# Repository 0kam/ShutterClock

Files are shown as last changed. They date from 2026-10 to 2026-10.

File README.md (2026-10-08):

# ShutterClock

定点カメラ（タイムラプス・フェノロジー観測）用の低消費電力インターバルタイマです。
Nikon デジタル一眼レフをリモート端子から有線レリーズし、12 V ソーラー充電バッテリーからカメラへ給電することもできます。
時刻合わせ・撮影スケジュール設定・撮影ログ回収は、スマホ（Android Chrome）の Web Bluetooth ページで行います。
積雪深ロガー [SnowGauge](https://github.com/0kam/SnowGauge) の姉妹プロジェクトです。

*ShutterClock is a low-power BLE interval timer for fixed-point cameras: XIAO nRF52840 (Zephyr), wired Nikon remote release via optocouplers, optional camera power from a 12 V solar battery, Web Bluetooth field app. Documentation is in Japanese.*

## 状態（2026-10-08）

基板 v1.0 を JLCPCB に発注済み（5 枚、10 月中旬到着予定）。回路は独立レビュー済み、ブレッドボードでの実機確認はこれから。初期決定事項と未決事項を [設計仕様書 v0.12](ShutterClock_設計仕様書_v0.12.md) にまとめています。
対象機種は D7200・D7500（必須）と D7000・D7100・D800・D810（任意）。D7500 の消費電流は実測済み。次は部品の到着後にブレッドボードで降圧モジュール・時計保持経路・撮影検出を確認し、ファームウェアを SnowGauge から流用します。

## 開発者向け

- 設計仕様書（要件・設計判断・未決事項・改版履歴）: [ShutterClock_設計仕様書_v0.12.md](ShutterClock_設計仕様書_v0.12.md)
- 部品購入リスト（ブレッドボード試作）: [docs/01_parts.md](docs/01_parts.md)（[CSV](docs/01_parts.csv)）
- SnowGauge から流用したファイルの一覧: [PROVENANCE.md](PROVENANCE.md)
- 作業引き継ぎ（AI エージェント向け）: [CLAUDE.md](CLAUDE.md)

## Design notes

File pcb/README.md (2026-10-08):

# ShutterClock PCB v1.0 (ordered 2026-10-08, JLCPCB W2026100808086019 / Y14-13437881A, 5 pcs)

- Board: **100 x 88 mm**, 2-layer. Bottom layer is a GND pour; most signals on top,
  the VIN trunk and a few long signals on the bottom.
- Mounting: 4x M3 (3.2 mm) holes, centres 3.5 mm from each edge (93 x 81 mm spacing).
- Generated by [generate_board.py](generate_board.py) (+ [tracks.py](tracks.py)) →
  `ShutterClock.kicad_pcb` (KiCad 10). **Never hand-edit the .kicad_pcb.**
  Run: `/Applications/KiCad/KiCad.app/Contents/Frameworks/Python.framework/Versions/Current/bin/python3 generate_board.py`
  then `kicad-cli pcb drc --severity-error --severity-warning --format json --output drc.json ShutterClock.kicad_pcb`
  and `python3 drc_report.py`. Current state: **DRC 0 errors, 0 unconnected** (46 warnings: silkscreen overlaps, library-name notes).
- Gerbers: `ShutterClock_v1.0_gerbers.zip` (JLCPCB: 2 layers, 1.6 mm, HASL, defaults). Renders: `render_top.png`, `render_bottom.png`.
- Circuit: spec v0.11 §6 (independent review applied). BOM: `../docs/01_parts.md`.

## Open items (ordered before bench verification — check these when the boards arrive)

1. U2 (MBC2596-01) hole positions (±19.0 / ±8.0 mm from the module centre) were judged
   correct by the user from the module photo; confirm with the real module on the bare board.
2. Bench-verify the circuit on the breadboard first (spec §6.5): LM2596 + 4700 µF with the
   D7500 (and D7200), keep-alive follower voltage, shot detection on A1.
3. Independent layout review (as for SnowGauge v1.2) — not done yet.
4. XIAO SMD-pad clearance to the KA_EN / CAM_EN tracks is at the 0.2 mm minimum; fine for
   JLCPCB but do not tighten.

## Firmware pin map (single source of truth for the board)

| XIAO pin | Net | Function |
|---|---|---|
| A0 (D0) | ADC_NODE | Battery voltage: VIN × 100k/(1M+100k) (ungated divider, 100 nF). Reading × 11 |
| A1 (D1) | A1_NODE | Camera current: 0.1 Ω low-side shunt in the camera return (CAM_N), 10 kΩ + 100 nF. 1 A = 0.1 V |
| D2 | AF_DRV | PC817 U4 (AF / half-press) via 1 kΩ. High = pressed |
| D7 | CAM_EN | Camera supply: Q3 → Q2 → MBC2596-01 (9.4 V) → 1N5822 → CAM_P. High = on |
| D8 | SHUT_DRV | PC817 U3 (SHUTTER / full-press) via 1 kΩ. High = pressed |
| D9 | BTN | Test-shot / BLE button SW1 to GND (enable the internal pull-up) |
| D10 | KA_EN | Keep-alive path: Q6 → Q5 → 10 Ω → Q7 follower (≈ 7.3–8.5 V) → CAM_P. High = on |
| 3V3 | 3V3_SYS | From U1 (NJW4181U3-33B) through JP1 |
| GND | GND | |
| D3–D6, 5V | — | unused (reachable on the XIAO castellations) |

Rules: never drive CAM_EN and KA_EN so that the camera is released on the keep-alive
path; enter keep-alive only from CAM_EN = on; drop to CAM_EN = on if A1 shows > 50 mA
during keep-alive; low-battery cutoff 11.5 V.

## Connectors and jumpers

- J1 (5.08 mm screw terminal, bottom-left): battery + / − (12 V lead-acid / LiFePO4; fuse F1 5 A, Q1 reverse protection, 2x P4KE15A TVS)
- J2 (5.08 mm screw terminal, bottom-right): camera + / − → Nikon EP-5B cable. The − side is the sense shunt — keep it as the only camera ground.
- J3 (3.5 mm stereo jack, right edge): tip = SHUTTER, ring = AF, sleeve = common → off-the-shelf 3.5 mm → MC-DC2 / 10-pin release cables (verify the cable's pinout with a meter)
- JP1 (near the XIAO): shunt fitted normally; **remove before connecting USB** to the XIAO (same rule as SnowGauge)
- JP2 (below Q3): shunt fitted = camera supply always on (bypasses Q3)
- U2: 4-pin module socket positions; set the trimpot to **9.4 V** and remove the module's LED before fitting

## Silkscreen notes

"REMOVE JP1 BEFORE USB", "U2: SET 9.4V, REMOVE LED", "JP2=ALWAYS ON", battery and camera polarity, diode cathodes marked "K".

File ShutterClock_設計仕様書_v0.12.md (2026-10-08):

# ShutterClock 設計仕様書 v0.12

- 版: v0.12(2026-10-08)
- 名称: **ShutterClock**
- 目的: 定点カメラ(タイムラプス・フェノロジー観測)の Nikon デジタル一眼レフを、低消費電力タイマで決まった時刻に有線レリーズする。必要に応じてソーラー充電の 12V バッテリーからカメラへ給電する
- 姉妹プロジェクト: SnowGauge(commit `36e21f8` / FW `fw-2026-09-07b` から分岐。流用ファイルは `PROVENANCE.md` に記録)
- 運用ポリシー: 本仕様書を唯一の真実(single source of truth)とし、変更時は毎回版を上げる

---

## 1. 位置づけ

- SnowGauge で実証済みの基盤(Zephyr FW、時計モデル、LittleFS 記録+内蔵フラッシュミラー、BLE アドバタイズ、SMP、WDT・診断、Web Bluetooth ページ)を流用し、「センサ測定」の代わりに「カメラのレリーズ」と「カメラ電源の制御」を行う。
- 撮影 1 回ごとに本体側にもレコードを残し、画像の EXIF 時刻と照合できるようにする(カメラ時計のずれ、撮り損ねの検出)。

## 2. 初期決定事項(2026-10-06 時点)

| 項目 | 決定 |
|---|---|
| 対象機種 | **必須: D7200、D7500**。対応したい: D7000、D7100、D800、D810(§2.1) |
| MCU | Seeed XIAO nRF52840(非 Sense で可)、NCS v3.4.0 / Zephyr。Adafruit ブートローダ維持、MCUboot なし、書き込みは USB シリアル DFU のみ |
| レリーズ | Nikon リモートケーブル 3 線(GND / AF / SHUTTER)、フォトカプラ 2 個(AF、SHUTTER)、スリープ中は両方 OFF。シーケンス: AF ON → 待ち(カメラ起床、300〜500ms 目安、実機で調整)→ SHUTTER ON(~200ms)→ 両方 OFF。AF を常時 GND に落とすのは禁止(半押し状態が続き測光が眠らない) |
| レンズ | MF(AF の合焦待ち・合焦失敗によるレリーズ不可を避ける) |
| 入力電源 | 12V 鉛 / LiFePO4、ソーラーチャージコントローラ経由。入力側の全部品を 30V 以上の定格で設計(充電時 14.8V、バッテリー外れ時の PV 開放電圧)。ヒューズ + TVS + P-MOSFET 逆接保護(カメラ系 2A 以上) |
| 3.3V | 30V 以上入力の低 Iq LDO(SnowGauge の NJU7223 は 14V 定格で不可) |
| カメラ電源 | 9V の降圧モジュール(EN 付き)をピンヘッダ実装し(v0.4: D7500 のピーク 3〜4A を実測。2A 級の D36V28F9 は不足。v0.7 案は秋月の LM2596 モジュール MBC2596-01 + 4,700µF、§6.2・U28)、Nikon のダミーバッテリー(カプラー)へ給電。EN は GPIO、ジャンパで常時 ON も選べる。9V 出力の電流検出は任意(カメラ起動・カード書き込み完了の判定用)。常時給電か撮影ごと給電かは待機電流の実測後に決める(U8) |
| 電池電圧監視 | ゲート付き分圧。30V 入力時に ADC ノード < 3.0V |
| スケジュール・BLE・SMP・現地ページ | SnowGauge と同じ構成と UI ルール(大きなボタン、ピッカー、破壊的操作は 2 タップ)。BLE 名 `SC-XXXX`。ページは https://0kam.github.io/ShutterClock/app/ |
| 記録 | 1 トリガ 1 レコード(時刻、seq、flags、vbat、温度、カメラ電流(実装時))→ EXIF 時刻と照合 |
| 工程 | 実カメラでブレッドボード → 実測(picowatt)→ PCB(`pcb/generate_board.py` で生成、手編集禁止、kicad-cli で DRC、JLCPCB 用ガーバー zip)→ 発注前に独立設計レビュー。**ShutterClock はユーザー本人が組み立てる(学生組立ではない)ので表面実装部品も可(v0.9)**。SnowGauge のスルーホール優先ルールは本機には適用しない |

### 2.1 対象機種と機種差(v0.2)

| 機種 | 優先 | リモート端子 | 電池 / ダミーバッテリー | USB(カメラ側、純正ケーブル) | 内蔵無線 |
|---|---|---|---|---|---|
| D7200 | 必須 | アクセサリーターミナル(MC-DC2 系) | EN-EL15 系 / EP-5B | 8 ピン独自形状(UC-E6 / UC-E17) | Wi-Fi + NFC |
| D7500 | 必須 | アクセサリーターミナル(MC-DC2 系) | EN-EL15a / EP-5B | micro-B(UC-E20) | SnapBridge(BLE + Wi-Fi) |
| D7000 | 任意 | アクセサリーターミナル(MC-DC2 系) | EN-EL15 / EP-5B | mini-B(UC-E4) | なし |
| D7100 | 任意 | アクセサリーターミナル(MC-DC2 系) | EN-EL15 / EP-5B | 8 ピン独自形状(UC-E6) | なし(WU-1a アダプタ) |
| D800 | 任意 | 10 ピン | EN-EL15 / EP-5B | USB 3.0 micro-B | なし |
| D810 | 任意 | 10 ピン | EN-EL15 系 / EP-5B | USB 3.0 micro-B | なし |

- **電源は 6 機種とも EN-EL15 系 + EP-5B(パワーコネクター)で共通**。純正 AC アダプタ EH-5b 系は 9V 出力なので、本体側の 9V 降圧で全機種をまかなえる。
- **レリーズは 6 機種とも同じ 3 線(GND / 半押し / 全押し)**で、違うのはカメラ側のコネクタだけ。10 ピンは 4 番 = 全押し、9 番 = 半押し、6 番 = 信号 GND(pinouts.ru の MC-22 ピン配置。現物で要確認)。→ 接続方式は U27。
- USB は機種ごとに形が違うので、§4.2 の案では「スマホ用 OTG アダプタ(USB-C → USB-A メス)+ 各機種の純正ケーブル」を使う。

## 3. 未決事項

決め方: 【実機】実カメラ・ブレッドボードで測って決める /【判断】使い方・運用で決める /【調査】データシート・資料で決まる。§5 の測定番号 M# と対応。

### 3.1 カメラ本体(最優先: ほぼすべてがこれで決まる)

| # | 項目 | 論点 | 決め方 |
|---|---|---|---|
| ~~U1~~ | ~~対象カメラ機種~~ | **解決(v0.2)**: 必須 D7200・D7500、任意 D7000・D7100・D800・D810(§2.1) | — |
| U2 | AF → SHUTTER のタイミング | 半押しタイマーオフ(スタンバイ)からの起床時間、SHUTTER パルス幅の下限、連続トリガの最小間隔 | 【実機】M3 |
| U3 | 消費電力 | **D7500 実測(v0.4、`docs/measurements/2026-10-07_d7500_current.md`)**: 9V 給電で待機(半押しタイマーオフ)= 電源スイッチ OFF = **0.42mA**(測定中に 0.60 → 0.42mA へ低下。時計リセット直後だったので時計用電池の充電分と推定)。1 ショット(MF、半押しタイマー 4 秒)**2.7A·s ≈ 0.75mAh@9V**、うち約 85% は撮影後に起きている約 10 秒。半押しタイマー 6 秒だと 3.2A·s。AF は +3% 程度。電源スイッチ ON / OFF のたびにセンサークリーニング(約 2 秒、各 1.2〜1.3A·s)。残: D7200 | 【実機】M1, M2 |
| U4 | 給電再投入時の挙動 | **D7500 実測(v0.4)**: 電源スイッチ ON のまま給電すると**自動で起動する**(0.54 秒で起床、センサークリーニングなし)。リモートを全押しにしたまま給電すると **1.95 秒後にレリーズ**(起動〜撮影可能の上限値)。残: D7200、時計リセット状態(日時設定画面)でもレリーズできるか | 【実機】M4 |
| U5 | カメラ内蔵時計の保持 | 時計は内蔵の充電式電源で動き、主電池(または EP-5B 給電)から必要に応じて充電される(Nikon 説明書)。撮影ごと給電で 1 日の通電が数分しかないと、充電が足りず数か月で時計がリセットされる恐れ(D7000〜D7200 の説明書では「約 2 日の充電で約 3 か月」、要確認)。待機電流が 0.60 → 0.42mA へ下がった実測(v0.4)は、待機中も時計用電池が充電されることを示唆する。**実例(v0.4)**: 試験に使った D7500 は電源 ON 時に日時設定画面を出した(しばらく電池なしで置かれ、時計がリセットされていた)。対策候補: 定期的に一定時間通電する、常時給電にする、**時刻の正は ShutterClock のレコードとし、ファイル番号とレコードを 1 対 1 で対応づける**(U10 の撮影検出が前提) | 【実機】M5【判断】 |
| U6 | カメラ設定チェックリスト | 撮影直後の画像表示、半押しタイマー、ファイル番号の連番、画質と SD 容量(撮影数/日 × 期間 × ファイルサイズ)、日時、MF 設定などを設置手順書にまとめる | 【判断】U1 後 |

### 3.2 カメラ電源方式

| # | 項目 | 論点 | 決め方 |
|---|---|---|---|
| U7 | ダミーバッテリーの種類 | 全機種 EP-5B で共通(v0.2)。純正 EP-5B + 本体の 9V か、互換品(12V 直入力や USB-C 給電のものもある)か。12V 直入力品なら降圧モジュールが不要になり、ハイサイドスイッチだけで済む。互換品は機種(特に D7500)で認識されない恐れ | 【調査】【実機】 |
| U8 | 常時給電 vs 撮影ごと給電 | 撮影ごと給電なら「EN ON → 起動待ち → AF/SHUTTER → 書き込み完了待ち → EN OFF」。書き込み中に切ると画像・カード破損の恐れがあるので、完了判定(固定の待ち時間か電流検出か)が必要。D7500 実測(v0.4)、1 日 6 ショット・9V 側: 常時給電 ≈ 15mAh/日 ≈ 0.13Wh/日 + 降圧モジュールの自己消費(D36V50F9 は 12V で 0.6〜1.2Wh/日、カメラより大きい)。撮影ごと給電(書き込み直後に切る、1 回約 2.5 秒)≈ 0.013Wh/日。12V 20Ah(240Wh)+ ソーラーに対してはどちらも小さく、効くのはパネルが数か月覆われる場合だけ。撮影ごと給電の残課題: 書き込み完了の判定、時計用電池の充電不足(U5)。**推奨(v0.4、未決): 既定は常時給電(単純、時計が保たれる、書き込み中の遮断がない)、EN 制御は残して低電圧時のカメラ遮断と撮影ごと給電モードに使う** | 【判断】 |
| U28 | カメラ電源のピーク電流 | **D7500 実測(v0.4)**: 1 ショットでピーク 3.0〜3.2A(最大 4.1A、2A 超が 20〜30ms、ミラー・シャッターチャージ時)、電源スイッチ ON 時 3.9A。**安定化電源の電流制限 2A ではレリーズせず「Err」**、4A なら正常。D36V28F9(連続 2.6A 標準)は不足 → 候補だった D36V50F9 は国内で取り扱いなし(v0.5 調査)→ **v0.7 案: 秋月の LM2596 モジュール MBC2596-01(¥1,900、ピーク電流制限 3.4A 以上、制限時も停止しない)+ 4,700µF**。予備 DFR1015 / D30V33MAS(§6.2 に必要容量の計算)。実物で撮影できるかはブレッドボードで確認 | 【実機】 |
| U29 | 時計保持用の微小電力経路 | U2(LM2596)の Iq 5mA では時計保持の通電(1 時間/日)が年 24Wh になる(§6.2)。**v0.9 案: 2SJ334 スイッチ + 2SK4017 フォロワ + ツェナー基準の別経路で 8〜9V を供給、U2 出力にショットキーで逆流防止(§6.1)**。必要な通電時間の根拠: Nikon の説明書(D7000〜D7200)の「約 2 日の充電で約 3 か月」(要確認)→ 比例なら 1 日あたり約 32 分、1 時間/日で 2 倍の余裕 | 【実機】M5 |
| U9 | 降圧モジュールの自己消費と EN の駆動 | D36V28F9 / D36V50F9 の資料値: 無負荷時 1〜3mA / 2〜4mA、スリープ時は EN→VIN の 100kΩ プルアップ等で 10〜20µA/V(12〜14.8V で約 120〜300µA)。**EN は VIN にプルアップされているので GPIO に直結しない**(GPIO に VIN が回り込む)。N-MOSFET のオープンドレインで引き下げる。MCU 停止時にカメラ電源を ON / OFF のどちらに倒すか、上流にロードスイッチを入れて µA 級まで切るかを決める | 【判断】【実機】M6 |

### 3.3 撮影成否の確認

| # | 項目 | 論点 | 決め方 |
|---|---|---|---|
| U10 | 撮れたことの検出 | **v0.5 案: (a) をカメラ側 GND の 0.1Ω シャントで実装(§6)。1A 超 = レリーズした、待機レベルに戻った = 書き込み完了 → 撮影ごと給電の遮断判定にも使う。** U5 の「レコードを時刻の正とする」方式を採るなら必須。(a) 9V 出力の電流検出(シャント + INA 系。カード書き込みの電流波形で判定、撮影ごと給電の完了判定にも使える)/ (b) ホットシューの X 接点(シンクロ接点)を GPIO で読む(露光時に閉じる。安価でスルーホール可。高速シャッター時の挙動と GND 共通化は要確認)/ (c) 検出しない(後で EXIF と照合) | 【判断】【実機】 |
| U11 | 失敗時の扱い | 未検出時の再試行回数、電池低下時に撮影をスキップする閾値、スキップ理由のレコード化 | 【判断】 |

### 3.4 入力電源・電源回路

| # | 項目 | 論点 | 決め方 |
|---|---|---|---|
| U12 | 電源の取り口 | チャージコントローラの LOAD 端子(コントローラの低電圧遮断に任せる)か、バッテリー直結(ファームで低電圧遮断)か。LOAD 端子だと遮断・復帰のたびに本体がリセットされる(時計は SnowGauge と同じ ESTIMATED 復帰で足りるか) | 【判断】 |
| U13 | バッテリー・パネル・コントローラ | **v0.5: 主に鉛 12V 20Ah、寒くない場所では LiFePO4 も使う。目標は 20Ah で約 1 年(ソーラーなしでも)。** 容量・機種は未定。LiFePO4 は 0°C 未満で充電不可(冬季運用ならコントローラの低温充電保護が必要)、鉛は温度補償 | 【判断】 |
| ~~U14~~ | ~~3.3V LDO の選定~~ | **決定(v0.9)**: NJW4181U3-33B(SOT-89、35V / 40V abs、Iq 9µA、¥60、秋月 113996)を基板に直接実装。ユーザーが組み立てるので表面実装可。入力に 100Ω + 10µF の RC(§6.1) | — |
| U15 | サージ・逆接保護の整合 | **v0.5 案: 秋月の TVS は P4KE15A まで → 2 本直列(スタンドオフ 25.6V、クランプ約 42V)。LDO(40V)の前に 47Ω + 10µF の RC を入れて保護。逆接保護は 2SJ334 + 15V ツェナー(§6)。** TVS のスタンドオフ電圧(> 14.8V、PV 開放電圧も考慮)とクランプ電圧に、LDO・降圧モジュール・MOSFET が耐えるか。逆接保護 P-MOSFET の Vgs 定格(30V 入力ならツェナーでゲートをクランプ) | 【調査】 |
| U16 | 電池分圧のゲート方式 | **v0.5 案: ゲートで切らず 1MΩ / 100kΩ を常時接続(12µA、予算の約 1%)。ADC ノードは 30V 入力で 2.7V、定格超過の経路がない(§6)。** 参考: ローサイドで切ると OFF 時に ADC ノードが入力電圧まで引き上げられる(nRF52840 の絶対最大定格違反。SnowGauge 仕様書 v0.10 で独立検証により見つかった件と同種)。ハイサイド(P-MOSFET + レベルシフト)で切るなど、OFF 時もノードが VDD を超えない構成にする | 【調査】 |

### 3.5 スケジュール・ファームウェア・アプリ

| # | 項目 | 論点 | 決め方 |
|---|---|---|---|
| U17 | スケジュールの表現 | **v0.5: 典型は 7〜18 時に毎時 1 枚(12 枚/日)→ (b) で表せる。** (a) 時刻リスト(例 10:00 / 12:00 / 14:00)、(b) 時間窓 + 間隔(SnowGauge 型)、(c) 日の出・日の入り基準(同期時の緯度経度から本体で計算)。併用可。最短間隔は U4・U8 で制約される | 【判断】 |
| U18 | 1 トリガあたりの枚数 | N 枚連続レリーズするか(カメラ側の露出ブラケットとの組み合わせ) | 【判断】 |
| U19 | 設置作業モード | アプリから「カメラ電源 ON(N 分後に自動 OFF)」「テスト撮影」「AF のみ」。撮影ごと給電にするなら、フレーミング中にカメラを起こしておく手段が必須 | 【判断】 |
| U20 | レコード形式 | SnowGauge は 40B 固定 + CRC-16。候補項目: UNIX 時刻、seq、flags(時計状態、撮影確認、スキップ理由、再試行)、vbat(無負荷 / カメラ負荷時)、温度(nRF 内蔵)、カメラ電流ピーク・書き込み時間、起床〜完了の所要時間 | 【判断】 |
| U21 | アドバタイズの中身 | 電池電圧、撮影数、最終撮影の成否、時計状態など | 【判断】 |
| U22 | チャンネル数 | カメラ 1 台固定か、2 チャンネル(2 台・別スケジュール)を用意するか。フォトカプラとコネクタの追加だけなので基板設計前に決めたい | 【判断】 |
| ~~U27~~ | ~~リモートケーブルの接続方式~~ | **決定(v0.3)**: 本体に 3.5mm ステレオジャック(スルーホール)を付け、インターバロメータ用に市販されている「3.5mm → MC-DC2」「3.5mm → 10 ピン」ケーブルで全機種に対応する。チップ / リング / スリーブの割り当て(一般にチップ = 全押し、リング = 半押し、スリーブ = GND)は購入品をテスターで確認する | — |
| U23 | テスト撮影画像の確認 | §4 の案のどれを採るか | 【判断】【実機】M7 |

### 3.6 筐体・設置・その他

| # | 項目 | 論点 | 決め方 |
|---|---|---|---|
| U24 | 筐体 | カメラハウジング(市販 / 自作)と制御箱の分け方、ケーブルグランド、結露・レンズの曇りや霜(ヒーターは電力収支に大きく効く) | 【判断】 |
| U25 | 運用条件 | 使用温度範囲(カメラのカタログ値は多くが 0〜40°C)、設置期間、巡回頻度 | 【判断】 |
| U26 | ライセンス | public リポジトリ(SnowGauge も未設定)。例: ファーム・アプリ MIT、基板 CERN-OHL-P | 【判断】 |

## 4. テスト撮影と画像確認(案)

### 4.1 基本(追加ハードなし)

アプリの「テスト撮影」ボタン(BLE)→ 本番と同じ有線レリーズ経路で撮影 → カメラ背面液晶の再生で確認。成否は U10 の検出があればアプリに表示する。

### 4.2 推奨候補: Android の USB OTG + WebUSB でカメラから直接画像を取る(本体ハード追加なし)

- 設置時だけ、スマホ(Android の Chrome)とカメラの USB 端子を OTG ケーブルでつなぐ。同じ Web ページが WebUSB で PTP(Picture Transfer Protocol)を話す。ShutterClock 本体には何も足さない。
- 流れ: BLE で ShutterClock にテスト撮影を指示(本番のレリーズ経路を試せる)→ PTP で新しい画像の追加を待つ → `GetThumb`(埋め込みサムネイル、約 160×120)または `GetObject`(JPEG 本体)→ ページに表示して構図・ピントを確認。
- おまけ: カメラの時計を PTP の日時プロパティでスマホ時刻に合わせられる(EXIF 照合が楽になる)。電池残量・カード空き容量も読める。将来はライブビュー(Nikon 独自コマンド)でのフレーミングも可能。
- 実現性の根拠: Chrome の WebUSB は PTP(Still Image クラス)を遮断していない。Google の web-gphoto2(libgphoto2 を WebAssembly + WebUSB に移植)は Android と macOS で追加設定なしに動くとされる。
- 途中結果(v0.3、D7500): OTG アダプタでスマホとつないだ状態でもシャッターは切れた。ただしスマホ側がカメラを認識していたかは未確認(Android の「開くアプリ」の選択画面は出なかった)。PTP セッションを開いた状態での確認は web-gphoto2 デモで行う。
- 制約: Android のみ(iPhone は Bluefy を含め WebUSB 非対応 → 4.1 に縮退)。Windows はドライバの差し替えが必要。カメラの USB 端子にハウジング内で手が届く必要がある。USB 接続中に有線レリーズが効くかは機種依存(M7)。効かなければ PTP の `InitiateCapture` で撮る(この場合は本番経路の試験にならない)。
- 実装方針: web-gphoto2(WASM で数 MB、LGPL)は組み込まず、必要な PTP 操作(セッション開始、イベント待ち、オブジェクト一覧、サムネイル / 本体取得、日時設定)だけを JS で手書きする。数百行規模の見込み。
- 着手前の確認(コード不要): 手持ちの Android + OTG アダプタ + 各機種の純正 USB ケーブル(§2.1)で web-gphoto2 のデモ(https://web-gphoto2.rreverser.com/)を開き、接続・撮影・プレビューができるか見る。手順と記録表は `docs/measurements/2026-10-07_webusb_ptp_check.md`。ここで動けばこの案は筋が良い。
- 6 機種すべてに使える(USB ケーブルの形が違うだけ)のが、4.3 のカメラ内蔵無線に対する利点。

### 4.3 機種依存・代替

- カメラ内蔵無線を設置時だけ使う: 開発ゼロ。ただし別アプリで、ShutterClock のページとは統合されない。対象機種では D7500(SnapBridge)と D7200(内蔵 Wi-Fi。旧アプリ Wireless Mobile Utility が今のスマホで動くかは要確認)だけで、D7000 / D7100 / D800 / D810 には使えない。
- Wi-Fi SD カード(ezShare 等): 本体の改造は不要だが、別アプリと Wi-Fi の切り替えが要る。常時給電時の消費と信頼性に難があり非推奨。

### 4.4 将来案(重い): ShutterClock 自身を USB ホストにする

nRF52840 は USB デバイス専用なので、SPI 接続の USB ホストコントローラ(MAX3421E。Zephyr に UHC ドライバあり、USB ホストスタックは実験的)を足し、PTP を自前実装してサムネイル(数 KB)を BLE で送る。巡回時にハウジングを開けずに最新画像を確認できるのが利点だが、ハード・ファーム・消費電力がすべて増えるため v1 では見送る。

## 5. 最初の実測(実カメラ + 安定化電源 + picowatt)

| # | 測るもの | 方法 | 決まる未決事項 |
|---|---|---|---|
| M1 | カメラ待機電流(電源スイッチ ON・半押しタイマーオフ / スイッチ OFF) | 安定化電源 9V → EP-5B、picowatt で電流 | U3, U8 |
| M2 | 1 ショットの電流プロファイル(起床・露光・カード書き込み)と mAh | 同上、リモートケーブルの AF/SHUTTER を手動スイッチで | U3, U8, U10 |
| M3 | スタンバイから AF → 撮影可能までの時間、SHUTTER パルス幅の下限 | フォトカプラ + 手元の MCU で遅延を振る | U2 |
| M4 | 給電再投入 → 自動起動の有無と撮影可能までの時間 | 電源 ON/OFF を繰り返す | U4, U8, U17 |
| M5 | 長時間無給電後の時計保持 | 一晩〜数日無給電にして日時を確認 | U5 |
| M6 | 降圧モジュールの自己消費(EN=Low / 無負荷、12V 入力) | picowatt | U9 |
| M7 | USB(PTP)接続中に有線レリーズが効くか、web-gphoto2 デモの動作 | Android + OTG アダプタ + 純正 USB ケーブル(`docs/measurements/2026-10-07_webusb_ptp_check.md`) | U23 |

測定はまず必須機種の D7200・D7500 で行い、任意機種は M7(数分で済む)だけでも見ておく。

実施状況(v0.4): M1・M2・M4 を D7500 で実施(`docs/measurements/2026-10-07_d7500_current.md`、picowatt 3200Sa/s、AF / MF、半押しタイマー 6 秒 / 4 秒)。M7 は OTG 接続中のレリーズのみ確認(§4.2)。

## 6. 回路・部品構成(v0.11、独立レビュー反映済み)

前提: 撮影ごと給電を既定(U8)、典型 12 枚/日、鉛 12V 20Ah で約 1 年。部品は秋月優先、次にスイッチサイエンス(SS)、海外通販は不可。**表面実装部品は可(v0.9、ユーザーが組み立てるため)**。カメラ電源出力はネジ端子(EP-5B のケーブルを直接つなぐ)。在庫・価格は 2026-10-07 時点。ピン割り当て・電気トポロジの正は今後 `pcb/README.md` に移す。

### 6.1 構成

```
J1 BAT+ ─ F1 5A ─ Q1 2SJ334(D→S、G は R15 1MΩ で GND、ZD1 15V G-S)─ VIN ─┬─ D1+D2 P4KE15A(直列)─ GND、C1 100µF/50V
                                                                      ├─ R4 100Ω ─ C2 10µF ─ U1 NJW4181 ─ C4 2.2µF ─ JP1 ─ XIAO 3V3(C6 0.1µF)
                                                                      ├─ R1 1MΩ ─ ADC_NODE(C7 0.1µF → A0)─ R2 100kΩ ─ GND
                                                                      ├─ Q2 2SJ334(S)…(D)─ U2 MBC2596-01(9.4V)─ D4 1N5822 ─┐
                                                                      │    Q2 G: R12 100kΩ → VIN、ZD2 15V G-S、R16 33kΩ → Q3 2SK4017 D(JP2 で常時 ON)
                                                                      │    Q3 G ← R8 1kΩ ← D2(CAM_EN)、R10 100kΩ → GND
                                                                      └─ Q5 2SJ334(S)…(D)─ KA_SW ─ R19 10Ω/1W ─ Q7 2SK4017 D、Q7 S ─────┴─ CAM+ ─ C3 4700µF、R17 1MΩ(ブリーダ)─ J2(+) → EP-5B
                                                                           Q5 G: R13 100kΩ → VIN、ZD3 15V G-S、R18 33kΩ → Q6 2SK4017 D
                                                                           Q6 G ← R9 1kΩ ← D10(KA_EN)、R11 100kΩ → GND
                                                                           Q7 G ← R5 47kΩ ← KA_SW、Q7 G ─ ZD4 9.1V ─ D6 1N4148 ─ GND(基準 ≈ 9.7V、Q5 ON 時のみ約 60µA)
J2(−)= CAM− ─ R3 0.1Ω 3W ─ GND(スター接続)、CAM− ─ R14 10kΩ ─ A1(C8 0.1µF)
D3(AF)─ R6 1kΩ ─ U3 PC817 ─ R20 100Ω ─ J3 リング      D8(SHUTTER)─ R7 1kΩ ─ U4 PC817 ─ R21 100Ω ─ J3 チップ      U3/U4 エミッタ ─ J3 スリーブ
D9 ─ SW1 ─ GND(テスト撮影・BLE 起動、内部プルアップ)     J4: D4/D5(I2C)・D6/D7・3V3・GND 予備ヘッダ
```

独立レビュー(2026-10-07、サブエージェント)で修正した点:
- Q2/Q5 のゲートと 2SK4017 の間に **33kΩ**(R16/R18)。Vgs は 11V で −8.3V(完全 ON)、14.8V で −11V(ツェナー非動作)、20V 以上で −15V にクランプ(30V で 0.45mA、ON 中のみ)。Q5 側にも ZD3。
- Q1 のゲート抵抗は **1MΩ**(10kΩ だと常時 1.1〜1.5mA = 年 150Wh 超)。向きは D = 電池側、S = VIN、ZD1 のカソードは S。
- 時計保持フォロワの基準は **KA_SW(Q5 の後)から R5 47kΩ** で取り、常時バイアスをなくす。ZD4 は 9.1V + 1N4148(10V ツェナーは秋月に無い)→ 基準 ≈ 9.7V、出力 ≈ 7.3〜8.5V(常に降圧より低く、Q2 ON 中は Q7 が電流を持たない)。Q7 ドレインに **10Ω/1W**(C3 への突入電流 ≤ 1.3A)。
- ファーム規則: 時計保持へは降圧 ON の状態からだけ入る(C3 が 9V のまま)、時計保持中はレリーズしない、時計保持中に A1 > 50mA なら Q2 ON に戻す。低電圧遮断は **11.5V**(11V では LM2596 がピーク時にドロップアウト)。
- **JP1**: U1 出力と XIAO 3V3 の間(USB 接続時に外す。シルク「REMOVE JP1 BEFORE USB」)。**JP2**: Q3 D-S 間(カメラ常時 ON)。
- フォトカプラ LED 抵抗は **1kΩ**(約 2mA。nRF52840 の標準駆動は 2mA)。J3 のチップ・リングに **100Ω** 直列。C3 に **1MΩ** ブリーダ。
- A0 分圧 1M/100k は 42V クランプ時に 3.8V(注入 0.2µA、C7 で緩和)→ 許容。SAADC: 内部 0.6V 基準、ゲイン 1/6、取得時間 ≥ 10µs、オーバーサンプル。基板ごとにゲイン定数を校正。
- 電流検出: ゲイン 1(FS 0.6V)で 1.46mA/LSB。R3 の GND 側・J1(−)・XIAO GND を 1 点で結ぶ(ケルビン配線)。カメラ GND への第 2 経路(ホットシュー等)は作らない。
- D4 の逆方向漏れ(1N5822: 0.1mA@25°C、高温で最大 1mA)は時計保持中に U2 側へ流れる → 温間で実測、大きければ低漏れ品か P-FET 理想ダイオードに。
- TVS 2 本直列のブレークダウンは 28.6〜31.6V: 30V 連続ならショート故障 → F1 が切れる(フェイルセーフ)。

- 3.3V は NJW4181U3-33B 1 段(動作 5〜35V、絶対最大 40V、Iq 9µA 標準 / 20µA 最大、100mA、±1%、サーマル・過電流・逆電流保護内蔵、Cin 0.1µF・Co 2.2µF セラミック可、−40〜+85°C、ピン 1 = VOUT / 2 = GND / 3 = VIN)。TVS クランプ(最大 42V)が絶対最大 40V を超えうるので、入力に R4 100Ω + C2 10µF の RC を置く(100Ω は BLE 送信の 15mA ピークでも 1.5V しか落ちない)。**代案(表面実装を避ける場合)**: Q4 2SK4017 フォロワ + 9.1V ツェナー + NJU7223F33 の 2 段(Iq 約 50µA)。
- カメラ系は Q2 で降圧モジュールの手前から切る(EN で止めるより漏れが少ない。SnowGauge の Q1/Q2 と同じ方式)。MCU 停止時は OFF 側に倒れる。ジャンパで常時 ON にもできる(ソーラーが十分な現場向け)。
- 撮影ごと給電のシーケンス(案): Q2 ON → AF+SHUTTER を保持(または約 2.5 秒待ってから AF → SHUTTER)→ R3 で 1A 超を検出 = レリーズ確認 → 待機レベル(< 50mA 程度)に戻るのを待つ = 書き込み完了 → Q2 OFF。
- **時計保持用の微小電力経路(U29)**: 撮影用の降圧 U2 は動作中に 5mA 食うので、時計の充電のためにカメラを待機状態(0.42mA)で 1 時間/日 通電する用途には使わない。代わりに Q5 → Q7(2SK4017 ソースフォロワ、ゲートをツェナー ZD4 で固定)の経路で約 8〜9V を供給する。消費は通電中のツェナーバイアス約 60µA とカメラ待機電流だけ(常時バイアスなし、v0.11)。U2 の出力には D4(ショットキー 1N5822、3A。5A のスルーホール品は秋月に無く、4A ピークは 20〜30ms なので可)を入れ、U2 が停止中に出力側から逆流しない(LM2596 は入力無電圧で出力に電圧がかかる状態を想定していない)ようにする。D4 の分だけ U2 は 9.4V に調整する。ZD4 は 9.1V + 1N4148(レビュー反映、v0.11)(出力 = Vz − Vgs ≈ 8〜9.5V を狙う)。
- 時計保持のシーケンス(案): 各撮影の書き込み完了後、Q5 ON → Q2 OFF(カメラは待機のまま、電圧 9 → 8〜9V)→ N 分後に Q5 OFF。12 枚/日 × 5 分 = 1 時間/日。追加の起動なし。N はアプリから設定可能にする。
- D4/D5(I2C)、D6/D7 は予備としてヘッダに出す。

### 6.2 カメラ用 9V(U28)

降圧モジュールの電流上限を超える分はコンデンサで補える。実測 17 ショットのうち最悪のケース(ピーク 4.1A)で、上限を超える電荷と、9V から 1V 下がるまでに必要な容量:

| 上限 | 超過電荷(最悪) | 必要容量(1V 低下) |
|---|---|---|
| 2.0A | 14.7mA·s | 約 15,000µF(非現実的。安定化電源 2A 制限で Err になったのと整合) |
| 2.5A | 3.7mA·s | **約 3,700µF → 4,700µF で可** |
| 3.0A | 0.7mA·s | 700µF |
| 3.3A | 0.5mA·s | 470µF |

ただし上限到達時にモジュールが「電流を抑えて出力を下げる」のか「停止(ヒカップ)する」のかで結果が変わるので、ブレッドボードで実物を確認する。

| 案 | 部品 | 入手 | 価格 | 評価 |
|---|---|---|---|---|
| **A(本命)** | **MBC2596-01**(HTC Korea、LM2596-ADJ 搭載、入力 4〜35V、出力 1.25〜30V を多回転ポテンショで調整、定格 2A・最大 3A、43×21mm、4 端子 IN+/IN−/OUT+/OUT−、基板上に 100µF/50V・220µF/35V・47µH、赤 LED)+ **C3 4,700µF/16V** | **秋月 131750** | ¥1,900 | **LM2596 のピーク電流制限は 3.6/4.5/6.9A(25°C)、全温度で 3.4A 以上**。制限時は周波数を下げて電流を抑える 2 段方式で、停止(ヒカップ)しない → 3.4A を超える分(最悪 0.5mA·s)はコンデンサで余裕をもって補える。動作時 Iq 5mA 標準 / 10mA 最大(ON/OFF ピンは端子に出ていないので Q2 で上流を切る)。IC の入力は動作 40V / 絶対最大 45V(TVS クランプ 42V 以下)。**LED(約 7mA)は外す。出力電圧は組立時にテスターで 9.0V に合わせ、ポテンショを固定する**。在庫 19(2026-10-07、10 月中旬補充予定) |
| B(予備) | DFRobot DFR1015(入力 7.5〜30V、9V 2.5A 連続 / 3.5A ピーク、出力はパッドで 9V 固定)+ C3 | SS 8601 | ¥1,172 | 搭載 IC・電流制限の挙動が未記載。調整不要なのは利点 |
| C(予備) | Pololu D30V33MAS(出力可変 → 9.0V、入力〜45V、3.3A 連続、EN、逆接 40V) | SS 9640 | ¥7,692 | 余裕はあるが高価 |
| 不可 | D36V50F9 / D36V28F9 | 国内取り扱いなし | — | — |
| 不可 | 秋月 AZ1084C-5.0(5A LDO) | 秋月 117599 | ¥50 | 入力 12V まで、TO-252(表面実装) |
| 不可 | 秋月の降圧キット(YDS512F など) | — | — | 入力 17〜20V 以上が必要 |

LM2596 の効率(資料の曲線): 入力 12V・出力 12V・3A で約 88%、出力 9V・0.3A 付近では 80〜85% と見る。動作時 Iq 5mA は撮影中(10 秒 × 12 回/日)なら無視できるが、**時計保持のために毎日 1 時間通電すると 5mA × 13V × 1h ≈ 0.065Wh/日(年 24Wh)になる**。秋月の 9V レギュレータ(NJM7809 / LM78L09 / BA09CC0T / BA90DD0T 等)はいずれも自己消費 mA 級で、NJW4181 の 8V 版は在庫がない → 低消費の 9V 降圧に替える道はないので、**時計保持は §6.1 の微小電力経路(U29)で行う(年約 3Wh)**。

### 6.3 部品表(草案、1 台分)

**購入リストの正は `docs/01_parts.md`(+ CSV、2026-10-07、秋月コード確認済み)**。以下は設計上の要点のみ。

| 記号 | 部品 | 型番 | 入手(コード) | 単価 | 備考 |
|---|---|---|---|---|---|
| A1 | マイコン | Seeed XIAO nRF52840(非 Sense) | 秋月 117341 | ¥1,780 | SS 8145 は品切れ |
| U1 | 3.3V LDO | **NJW4181U3-33B**(SOT-89-3、35V / 40V abs、Iq 9µA、100mA) | 秋月 113996 | ¥60 | U14 決定。基板に直接実装 |
| R4, C2 | U1 入力の RC | 100Ω 1/4W + 10µF/50V(電解または積セラ) | 秋月 | — | TVS クランプ 42V から U1(40V abs)を守る |
| U2 | 9V 降圧 | **MBC2596-01**(LM2596-ADJ モジュール、9.4V に調整、LED を外す) | 秋月 131750 | ¥1,900 | §6.2。予備 DFR1015(SS 8601)/ D30V33MAS(SS 9640) |
| D4 | U2 出力の逆流防止 | ショットキー 1N5822(40V 3A) | 秋月 102229 | 10 本 ¥350 | 時計保持中に U2 へ逆流させない。発熱が気になれば 2 本並列 |
| Q5, Q6 | 時計保持経路のハイサイドスイッチ | 2SJ334 + 2SK4017(Q2/Q3 と同じ) | 秋月 102846 / 107597 | ¥110 / ¥30 | GPIO D10 |
| Q7 | 時計保持用フォロワ | 2SK4017 | 秋月 107597 | ¥30 | 出力 ≈ Vz − Vgs ≈ 8〜9V、負荷 0.4〜0.6mA |
| ZD4, D6, R5 | Q7 ゲート基準 | 9.1V ツェナー BZX55C9V1 + 1N4148 + 47kΩ(KA_SW から) | 秋月 115721 / 100941 | 20 本 ¥100 / 50 本 ¥200 | バイアス約 60µA、Q5 ON 中のみ |
| Q1, Q2 | P-ch MOSFET | 2SJ334(−60V、38mΩ@−10V、±20V) | 秋月 102846 | ¥110 | ピン G-D-S |
| Q3 | N-ch MOSFET | 2SK4017(60V、Vth 1.3〜2.5V) | 秋月 107597 | ¥30 | ピン G-D-S |
| ZD1, ZD2 | Q1/Q2 ゲート保護 | 15V ツェナー GDZJ15C | 秋月 107498 | ¥10 | 入力 30V 超でも Vgs を 15V に制限 |
| D1, D2 | TVS(2 本直列) | P4KE15A | 秋月 129633 | 10 本 ¥150 | 合成でスタンドオフ 25.6V、クランプ約 42V(U15) |
| F1 | ヒューズ | 5.2×20mm 5A(普通溶断 MF51NR)+ クリップ FUC-03A ×2 | 秋月 107131 / 110521 | ¥40 / ¥20 | 5A のタイムラグ品は秋月になし。4A×30ms のピークは I²t で問題なし。クリップの電流定格は未確認 |
| R3 | 電流検出 | 0.1Ω 3W ±1%(RSMF3BR100F) | 秋月 111011 | ¥20 | 225mA → 22.5mV、4A → 0.4V |
| R1, R2 | 電池分圧 | 1MΩ / 100kΩ | 秋月(SnowGauge と同じ) | — | ゲートなし(U16) |
| U3, U4 | フォトカプラ | PC817X3NSZ1B(Sharp) | 秋月 113765 | ¥30 | 在庫少。代替 UPC817CG(116090) |
| J3 | 3.5mm ステレオジャック | MJ-8435 | 秋月 109060 | ¥90 | 1 = スリーブ、2 = チップ、3 = リング |
| C1 | 入力コンデンサ | 100µF/50V ハイブリッド(Rubycon 50PZF100M10X9) | 秋月 116871 | ¥80 | |
| C3 | 9V 側バルク | 電解 4,700µF/16V(Rubycon ZLH 16ZLH4700MEFC16X25、φ16×25mm、低インピーダンス品) | 秋月 114096 | ¥100 | §6.2。LM2596 の電流制限(最小 3.4A)を超えるピークの補償。計算上は 1,000µF で足りるが温度・D7200 未測定の余裕 |
| SW1 | タクトスイッチ | 6mm | 秋月 103647 | ¥15 | |
| J1, J2 | ネジ端子 2P 5.08mm | TB111-2 | 秋月 102333 | ¥40 | J1 電池、J2 カメラ電源(EP-5B のケーブルを直接。v0.6 決定) |
| — | ダミーバッテリー | Nikon EP-5B | Amazon.co.jp など国内 | 約 ¥2,300 | |
| — | レリーズケーブル | 3.5mm → MC-DC2 型 | Amazon.co.jp(例: 「3.5mm-N3」) | 約 ¥900 | チップ/リング/スリーブはテスターで確認。10 ピン用は国内に 3.5mm 品がなく 2.5mm 品 + 変換が必要 |

### 6.4 電力見積もり(12 枚/日、ソーラーなし)

| 項目 | 1 日あたり |
|---|---|
| ShutterClock(MCU・BLE・NJW4181・分圧・Q1 ゲート、約 50µA) | 0.016Wh |
| 撮影 12 回(1 回 ≈ 3.05A·s @9V、降圧効率 88%) | 0.10Wh |
| カメラ系 OFF 中(Q2 で遮断) | ≈ 0 |
| 時計保持 1 時間/日(U29 の経路、カメラ待機 0.42〜0.6mA @13V) | 0.006〜0.008Wh |
| **合計** | **約 0.13Wh/日 → 年約 47Wh** |

鉛 20Ah(240Wh)は放電深度 50%・自己放電を見込むと 1 年で使えるのは 60〜120Wh 程度 → ソーラーなしでもほぼ 1 年。LiFePO4 なら余裕あり。常時給電(降圧の無負荷電流が 24 時間流れる)は 1 年の目標に合わない。

### 6.5 ブレッドボードで確認すること(発注前)

1. MBC2596-01(9.0V に調整、LED 除去)+ 4,700µF で D7500(と D7200)が Err なく撮影できるか、撮影中の 9V の落ち込み(picowatt の vbus)、12V 入力時の無負荷電流
2. 撮影ごと給電のシーケンス(§6.1)と、R3 の電流でのレリーズ確認・書き込み完了の判定
3. NJW4181 + XIAO の待機電流(SnowGauge は NJU7223 込みで 32µA だった)
5. 時計保持経路: Q7 の出力電圧(ZD4 の値決め)、U2 停止中に D4 で逆流が止まること、待機状態の通電で時計用電池が充電されること(M5: 通電 1 時間/日で数週間後に時計が合っているか)
4. 購入したレリーズケーブルのチップ / リング / スリーブ

## 7. 進め方(案)

1. 対象機種は決定済み(§2.1)。EP-5B、リモートケーブル(U27)、OTG アダプタを用意する
2. M1〜M7 を測る(ブレッドボード以前、手動スイッチで可)→ U2〜U5、U7〜U9 を決める
3. 回路案(電源入力・LDO・降圧・フォトカプラ・分圧・電流検出)→ ブレッドボード
4. FW: SnowGauge から流用(`PROVENANCE.md` に記録)→ レリーズ・カメラ電源制御 → レコード → テスト撮影 / 状態 GATT → ページ
5. ブレッドボード実機で消費電流を実測 → PCB → 独立設計レビュー → 発注

## 8. 改版履歴

| 版 | 日付 | 内容 |
|----|---|---|
| v0.1 | 2026-10-06 | 初版。初期決定事項(§2)、未決事項 U1〜U26(§3)、テスト撮影画像の確認案(§4)、最初の実測項目 M1〜M7(§5) |
| v0.2 | 2026-10-06 | **対象機種を決定(U1 クローズ)**: 必須 D7200・D7500、任意 D7000・D7100・D800・D810。§2.1 機種差の表を新設(全機種 EP-5B 共通、レリーズは 3 線共通でコネクタのみ MC-DC2 系 / 10 ピン、USB 形状は機種ごと)。U5 に時計の充電式電源と「レコードを時刻の正とする」案、U7 を EP-5B 前提に、U9 に D36V28F9 の資料値と EN をオープンドレインで駆動する注意、U10 に U5 との関係、**U27(3.5mm ジャック + 市販変換ケーブル案)を追加**。§4.2 に明日の確認手順書へのリンク、§4.3 を対象機種の内蔵無線に合わせて更新 |
| v0.3 | 2026-10-07 | **U27 決定(3.5mm ジャック + 市販変換ケーブル)**。**D7500 の電流を実測(M1・M2)**: 待機 ≈ スイッチ OFF ≈ 0.60mA@9V、1 ショット 3.3A·s(約 8 割は撮影後の待機)、ピーク 3.1A(電源 ON 時 3.9A)、電流制限 2A で「Err」→ **U28(ピーク電流)を追加**、U3・U8 に実測値と判断の目安。§4.2 に OTG 接続中もレリーズできた途中結果 |
| v0.4 | 2026-10-07 | **D7500 の追加測定(AF / MF、半押しタイマー 6 / 4 秒、給電の入れ直し)**: 待機 0.42mA(時計リセット直後の 0.60mA から低下)、1 ショット 2.7A·s(MF・4 秒)、センサークリーニングは電源スイッチ ON / OFF のみ。**U4: 給電で自動起動、全押し保持で 1.95 秒後にレリーズ**。U5 に時計リセットの実例。U8 に 1 日あたりの見積りと推奨(既定は常時給電、未決)。**U28: 最大 4.1A、候補を D36V50F9 に**。§2 カメラ電源の行を更新 |
| v0.5 | 2026-10-07 | **§6 回路・部品構成案(草案)を新設**: 秋月・SS での入手性を調査(海外通販不可)。撮影ごと給電を前提に Q2 でカメラ系を遮断、9V は SS の Pololu D30V33MAS(D36V50F9 は国内取り扱いなし、秋月 AZ1084C は入力 12V まで)、3.3V は RT9069 / NJW4183(表面実装、40V)、TVS は P4KE15A ×2、電流検出 0.1Ω、分圧はゲートなし。12 枚/日で年 45〜65Wh の見積もり。U10・U13〜U17 に v0.5 の案と前提(典型 7〜18 時毎時、鉛 20Ah で 1 年)を追記。旧 §6・§7 を §7・§8 に |
| v0.6 | 2026-10-07 | ユーザー決定: **表面実装不可**、カメラ電源出力はネジ端子。§6.2 にピーク補償の計算(2.5A 上限なら 4,700µF で可、2.0A は 15,000µF で非現実的)→ **9V は DFRobot DFR1015 + 4,700µF を本命、D30V33MAS を予備**。**3.3V は 2SK4017 フォロワ + 9.1V ツェナー + NJU7223F33 の 2 段**(U14、代案 LP2950)。§6.1・§6.3・§6.5 を更新 |
| v0.7 | 2026-10-07 | **9V 降圧を秋月の MBC2596-01(LM2596-ADJ モジュール、ユーザー提案)に変更**: 資料とデータシートを確認(ピーク電流制限 3.4〜6.9A、2 段の周波数低減方式で停止しない、Iq 5mA、入力 40V、ON/OFF ピンは端子なし、LED 要除去、ポテンショで 9.0V に調整)。DFR1015 / D30V33MAS は予備に。§6.2 に時計保持通電と Iq 5mA の影響(年 24Wh)を追記 |
| v0.8 | 2026-10-07 | **3.3V LDO を NJW4181U3-33B(ユーザー提案)に変更(判断待ち)**: データシート確認(動作 5〜35V、絶対最大 40V、Iq 9/20µA、100mA、保護内蔵、セラミック可、ピン VOUT-GND-VIN)。SOT-89 を変換基板 AE-SOT89 に載せてスルーホール扱いにする案、入力に 100Ω + 10µF の RC。フォロワ + NJU7223F33 は代案に。§6.4 の本体消費を約 35µA に |
| v0.9 | 2026-10-07 | ユーザー決定: **ShutterClock は本人が組み立てるので表面実装可** → U14 クローズ(NJW4181U3-33B を基板に直接実装)。**U29 時計保持用の微小電力経路を追加**(秋月の 9V レギュレータは mA 級、NJW4181 8V 版は在庫なしのため): 2SJ334 + 2SK4017 フォロワ + ツェナー、U2 出力にショットキー D4、U2 は 9.4V に調整、撮影後に 5 分 × 12 回 = 1 時間/日。§6.1・§6.3・§6.4(年約 47Wh)・§6.5 を更新。U5 に説明書の「2 日で 3 か月」と待機中充電の示唆 |
| v0.10 | 2026-10-07 | ユーザー決定: 電圧下限の試験はせず 9V 方針を維持、U2 は MBC2596-01(DFR1015 より資料が揃い入力耐圧が高い)。**`docs/01_parts.md` + CSV を新設**(秋月コード・価格・在庫を確認)。D4 を 1N5822(3A)に、ZD4 を 12V に(5A スルーホール品・11V ツェナーは秋月に無い) |
| v0.11 | 2026-10-07 | **独立設計レビュー(サブエージェント)を反映**: Q2/Q5 ゲートに 33kΩ 直列 + Q5 にも 15V ツェナー(BLOCKER)、Q1 ゲート抵抗 1MΩ(BLOCKER、10kΩ は年 150Wh)、時計保持の基準を KA_SW から 47kΩ + 9.1V ツェナー + 1N4148 に(常時バイアス廃止)、Q7 に 10Ω/1W、JP1(USB)・JP2(常時 ON)、PC817 LED 1kΩ、J3 に 100Ω、C3 に 1MΩ ブリーダ、低電圧遮断 11.5V、ケルビン配線の注意。§6.1 を v0.11 回路に差し替え。PCB v1.0 草案を生成(`pcb/generate_board.py`、100×88mm、DRC エラー 0、ガーバー出力済み、未発注。U2 の穴位置は実測待ち、ピンマップは `pcb/README.md`) |
| v0.12 | 2026-10-08 | **PCB v1.0 を JLCPCB に発注**(注文 W2026100808086019 / PCB Y14-13437881A、2 層 100×88mm、5 枚、緑、1.6mm、HASL、1oz、合計 $13.75、UPS Express Saver 2〜4 営業日、配送先 自宅)。U2 の穴位置はユーザー確認済み。ブレッドボード検証とレイアウトレビューは基板到着までに並行して行う |

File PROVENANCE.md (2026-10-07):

# Provenance

Files copied from [SnowGauge](https://github.com/0kam/SnowGauge).
Fork point: commit `36e21f8` (FW `fw-2026-09-07b`).

When a bug is fixed on either side, check this table and port the fix by hand.
Add a row whenever a file is copied; update "Changes" when it diverges.

| ShutterClock path | SnowGauge source path | SnowGauge commit | Changes |
|---|---|---|---|
| `pcb/lib/XIAO-nRF52840-DIP.kicad_mod` | `pcb/lib/XIAO-nRF52840-DIP.kicad_mod` | `36e21f8` (file unchanged since `b0c9c5e`) | none — same XIAO footprint (14 through-hole pads, 15.24 mm rows) |
| `pcb/generate_board.py` (structure) | `pcb/generate_board.py` | `36e21f8` | rewritten for the ShutterClock netlist; same pcbnew approach (nets → footprints → tracks → outline → GND pour → silk) |

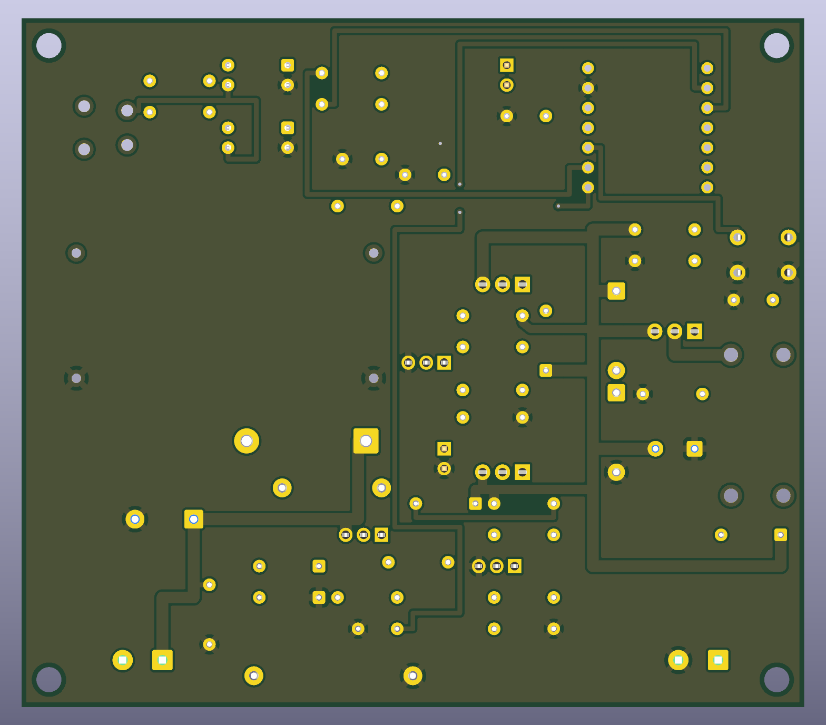
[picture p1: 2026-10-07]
pcb/render_bottom.png

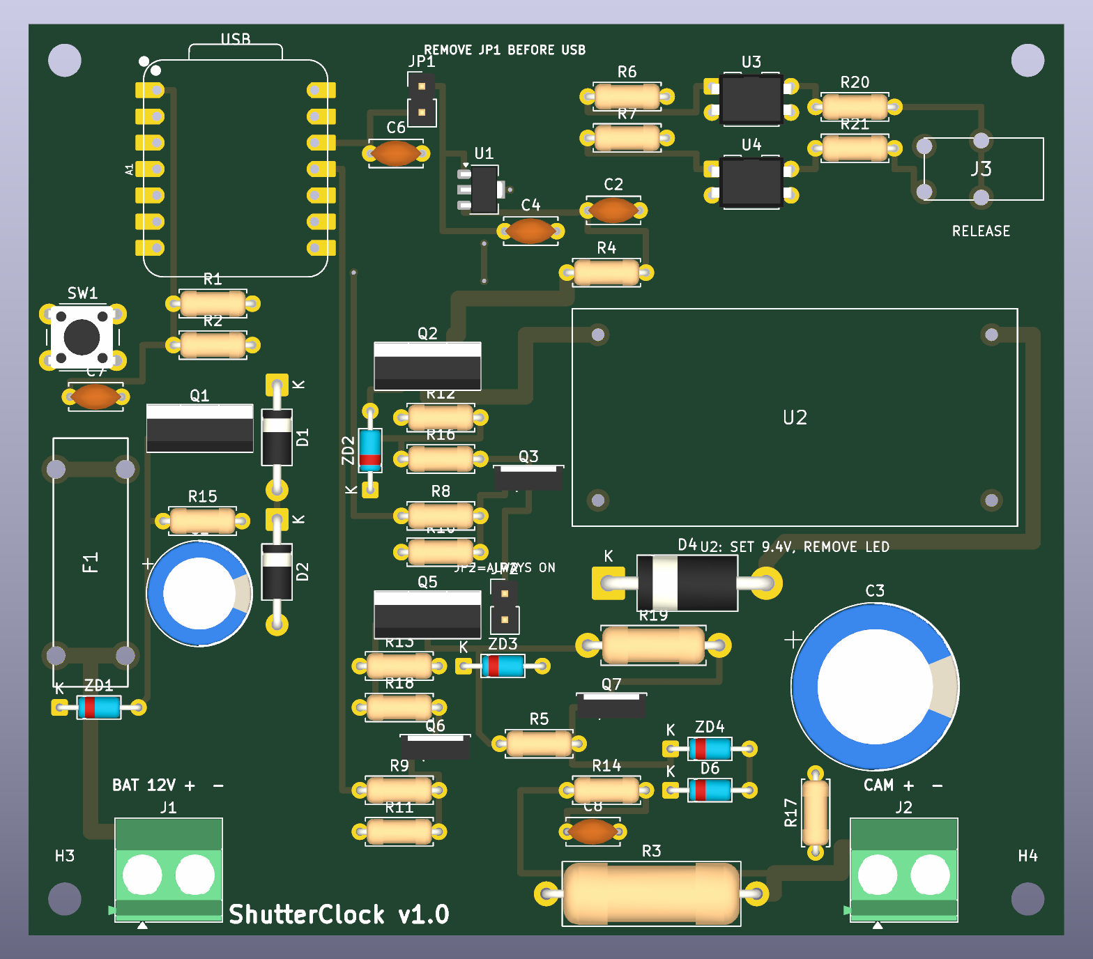
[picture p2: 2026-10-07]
pcb/render_top.png

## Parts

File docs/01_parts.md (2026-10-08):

# 01. 部品購入（ShutterClock 部品表 / BOM）

対象: **ブレッドボード試作（2026-10 発注分）**。回路は設計仕様書 v0.11 §6（独立レビュー反映済み）で、PCB 化の前にブレッドボードで検証します。
購入先は秋月電子を優先し、カメラ側のアクセサリは Amazon.co.jp です。価格・在庫は 2026-10-07 時点（税込）。

> 設計の根拠は [設計仕様書](../ShutterClock_設計仕様書_v0.12.md) §6、電気的なつながりの正は（PCB 設計後）`pcb/README.md` に移します。
> 注文用の CSV（同じ内容）: [01_parts.csv](01_parts.csv)

## 1. 買い方の目安

| 作るもの | 必要な表 |
|---|---|
| ブレッドボード試作（1 台） | (a) 回路部品 + (b) ブレッドボード用 + (c) カメラ側 |
| PCB 版（後日） | (a) + (d)。基板は JLCPCB |

秋月は 10 本・20 本・100 本売りの部品が多いので、「数量」は**回路 1 台に載る個数**、「備考」に販売単位を書いています。

## 2. 部品表

### (a) 回路部品（1 台分）

| 記号 | 部品 | 値/型番 | 数量 | 購入先 | 単価 | 備考 |
|---|---|---|---|---|---|---|
| A1 | マイコン（BLE） | Seeed **XIAO nRF52840**（非 Sense、秋月表記「XIAO BLE nRF52840」） | 1 | [秋月 117341](https://akizukidenshi.com/catalog/g/g117341/) | ¥1,780 | 在庫 269。予備 +1 推奨 |
| U1 | 3.3 V LDO（常時 ON） | **NJW4181U3-33B**（SOT-89、入力 5〜35 V、Iq 9 µA、100 mA） | 1 | [秋月 113996](https://akizukidenshi.com/catalog/g/g113996/) | ¥60 | 表面実装。ブレッドボードでは変換基板 AE-SOT89 に載せる（(b)） |
| U2 | カメラ用 9 V 降圧 | **MBC2596-01**（LM2596-ADJ モジュール、入力 4〜35 V、3 A） | 1 | [秋月 131750](https://akizukidenshi.com/catalog/g/g131750/) | ¥1,900 | **在庫僅少、10 月中旬入荷予定**。2 個買って 1 個予備。組立時に出力を **9.4 V** に調整、赤 LED を外す |
| Q1, Q2, Q5 | P-ch MOSFET（逆接保護 / カメラ電源スイッチ / 時計保持スイッチ） | **2SJ334**（−60 V / −30 A） | 3 | [秋月 102846](https://akizukidenshi.com/catalog/g/g102846/) | ¥110 | ピン G-D-S。10 個入り [115414](https://akizukidenshi.com/catalog/g/g115414/) ¥990 もある |
| Q3, Q6, Q7 | N-ch MOSFET（Q2/Q5 のゲート駆動 / 時計保持フォロワ） | **2SK4017(Q)**（60 V / 5 A） | 3 | [秋月 107597](https://akizukidenshi.com/catalog/g/g107597/) | ¥30 | ピン G-D-S。在庫あり（10 月上旬入荷予定の表示あり） |
| ZD1, ZD2, ZD3 | Q1 / Q2 / Q5 の G-S 保護 | 15 V ツェナー **GDZJ15C** 500 mW | 3 | [秋月 115169](https://akizukidenshi.com/catalog/g/g115169/) | 10 本 ¥90 | 単品は [107498](https://akizukidenshi.com/catalog/g/g107498/) ¥10 |
| ZD4 | 時計保持フォロワのゲート基準 | 9.1 V ツェナー **BZX55C9V1** 500 mW | 1 | [秋月 115721](https://akizukidenshi.com/catalog/g/g115721/) | 20 本 ¥100 | 1N4148 と直列で基準 ≈ 9.7 V → 出力 ≈ 7.3〜8.5 V（10 V ツェナーは秋月に無い） |
| D6 | ZD4 と直列（+0.6 V） | **1N4148** | 1 | [秋月 100941](https://akizukidenshi.com/catalog/g/g100941/) | 50 本 ¥200 | |
| D1, D2 | TVS（2 本直列） | **P4KE15A**（400 W、DO-41） | 2 | [秋月 129633](https://akizukidenshi.com/catalog/g/g129633/) | 10 本 ¥150 | 直列でスタンドオフ 25.6 V、クランプ最大約 42 V |
| D4 | U2 出力の逆流防止 | ショットキー **1N5822**（40 V / 3 A） | 1 | [秋月 102229](https://akizukidenshi.com/catalog/g/g102229/) | 10 本 ¥350 | 5 A のスルーホール品は秋月に無い。4 A のピークは 20〜30 ms なので 3 A 定格で可 |
| F1 | ヒューズ | ガラス管 **MF51NR 250 V 5 A**（5.2×20 mm） | 1 | [秋月 107131](https://akizukidenshi.com/catalog/g/g107131/) | ¥40 | 普通溶断。タイムラグ 5 A は秋月に無いが、4 A×30 ms のピークは問題なし |
| F1 ホルダ | ヒューズクリップ | **FUC-03A**（基板用、5.2 mm） | 2 | [秋月 110521](https://akizukidenshi.com/catalog/g/g110521/) | ¥20 | 2 個で 1 本分。箱型の MF-563（114929）は 4 A 定格なので使わない |
| R3 | カメラ電流検出 | **0.1 Ω 3 W ±1 %**（RSMF3BR100F） | 1 | [秋月 111011](https://akizukidenshi.com/catalog/g/g111011/) | ¥20 | 待機 0.42 mA → 42 µV、4 A → 0.4 V。ADC で読む |
| U3, U4 | フォトカプラ（AF / SHUTTER） | **PC817**（Sharp PC817X3NSZ1B） | 2 | [秋月 113765](https://akizukidenshi.com/catalog/g/g113765/) | ¥30 | 在庫僅少。代替 UPC817CG [116090](https://akizukidenshi.com/catalog/g/g116090/) ¥15 |
| J3 | レリーズ用ジャック | 3.5 mm ステレオミニジャック **MJ-8435**（基板取付） | 1 | [秋月 109060](https://akizukidenshi.com/catalog/g/g109060/) | ¥90 | 1 = スリーブ、2 = チップ、3 = リング |
| JP1, JP2 | USB 時に外す / カメラ常時 ON | ピンヘッダ 1×2 + ジャンパピン | 2 | （ピンヘッダは (b) の 1×40 を折る。ジャンパピン [秋月 103691](https://akizukidenshi.com/catalog/g/g103691/) 要確認） | — | JP1 = U1 → XIAO 3V3、JP2 = Q3 D-S |
| SW1 | テスト撮影 / BLE 起動ボタン | タクトスイッチ 6 mm（DTS-63-N-V-BLK） | 1 | [秋月 103647](https://akizukidenshi.com/catalog/g/g103647/) | ¥15 | |
| C1 | 入力バルク | **100 µF / 50 V** ハイブリッド（Rubycon PZF） | 1 | [秋月 116871](https://akizukidenshi.com/catalog/g/g116871/) | ¥80 | 安価な代替: ニチコン HE 100 µF/50 V [108440](https://akizukidenshi.com/catalog/g/g108440/) 5 本 ¥100 |
| C2 | U1 入力（RC の C） | **10 µF / 50 V** 積セラ（5 mm） | 1 | [秋月 108155](https://akizukidenshi.com/catalog/g/g108155/) | ¥60 | |
| C3 | カメラ 9 V 側バルク | **4,700 µF / 16 V**（Rubycon ZLH） | 1 | [秋月 114096](https://akizukidenshi.com/catalog/g/g114096/) | ¥100 | φ16×25 mm。ピーク補償 |
| C4 | U1 出力 | **2.2 µF / 50 V** 積セラ（5 mm） | 1 | [秋月 108152](https://akizukidenshi.com/catalog/g/g108152/) | ¥30 | NJW4181 の指定値以上 |
| C6〜C8 | XIAO パスコン・ADC フィルタ | **0.1 µF / 50 V** 積セラ | 3 | [秋月 113582](https://akizukidenshi.com/catalog/g/g113582/) | 10 個 ¥100 | U1 入力、XIAO、A0、A1 |
| R4 | U1 入力（RC の R） | **100 Ω** 1/4 W | 1 | [秋月 125101](https://akizukidenshi.com/catalog/g/g125101/) | 100 本 ¥200 | |
| R20, R21 | J3 チップ / リング直列（保護） | **100 Ω** 1/4 W | 2 | （R4 と同じ袋） | — | |
| R6〜R9 | フォトカプラ LED 直列 / Q3・Q6 ゲート直列 | **1 kΩ** 1/4 W | 4 | [秋月 125102](https://akizukidenshi.com/catalog/g/g125102/) | 100 本 ¥100 | |
| R10〜R13 | Q3 / Q6 プルダウン、Q2 / Q5 G-S プルアップ | **100 kΩ** 1/4 W | 4 | [秋月 125104](https://akizukidenshi.com/catalog/g/g125104/) | 100 本 ¥200 | SnowGauge の R4/R5 と同じ |
| R5 | ZD4 バイアス（KA_SW から） | **47 kΩ** 1/4 W | 1 | [秋月 125473](https://akizukidenshi.com/catalog/g/g125473/) | 100 本 ¥200 | 約 60 µA、Q5 ON 中のみ。コード要確認 |
| R16, R18 | Q2 / Q5 ゲート直列（ツェナー電流制限） | **33 kΩ** 1/4 W | 2 | [秋月 125333](https://akizukidenshi.com/catalog/g/g125333/) | 100 本 ¥200 | レビュー BLOCKER 1 の修正 |
| R19 | Q7 ドレイン（突入電流制限） | **10 Ω 1 W** カーボン | 1 | [秋月 107956](https://akizukidenshi.com/catalog/g/g107956/) | 100 本 ¥350 | 4,700 µF への突入 ≤ 1.3 A |
| R1, R15, R17 | 電池分圧（上）/ Q1 ゲート / C3 ブリーダ | **1 MΩ** 1/4 W | 3 | [秋月 125105](https://akizukidenshi.com/catalog/g/g125105/) | 100 本 ¥200 | |
| R2 | 電池分圧（下） | **100 kΩ** 1/4 W | 1 | （R10〜R13 と同じ袋） | — | 30 V 入力で ADC ノード 2.7 V |
| R14 | A1 の RC フィルタ | **10 kΩ** 1/4 W | 1 | [秋月 125103](https://akizukidenshi.com/catalog/g/g125103/) | 100 本 ¥100 | |

### (b) ブレッドボード用（試作のみ）

| 部品 | 値/型番 | 数量 | 購入先 | 単価 | 備考 |
|---|---|---|---|---|---|
| ブレッドボード 830 穴 | EIC-102BJ | 1 | [秋月 100285](https://akizukidenshi.com/catalog/g/g100285/) | ¥1,980 | ジャンパ付きセット EIC-102J [102314](https://akizukidenshi.com/catalog/g/g102314/) ¥1,280 でも可 |
| ジャンパワイヤ（オス–オス） | 60 本以上セット | 1 | [秋月 130088](https://akizukidenshi.com/catalog/g/g130088/) | ¥300 | カメラ電源系は短く太い線で（4 A ピーク） |
| SOT-89 変換基板 | AE-SOT89 | 1 | [秋月 110835](https://akizukidenshi.com/catalog/g/g110835/) | 10 枚 ¥70 | U1 をブレッドボードに挿すため |
| ピンヘッダ 1×40 | PH-1x40SG | 1 | [秋月 100167](https://akizukidenshi.com/catalog/g/g100167/) | ¥35 | XIAO、変換基板、MBC2596-01 の足に折って使う |
| 安定化電源 | 12〜15 V、電流制限 **4 A 以上** | 1 | 手持ち | — | 2 A 制限ではカメラが Err になる |
| picowatt | 手持ち | 1 | — | — | 電流プロファイル用 |
| テスター | DC 電圧 0.01 V 単位 | 1 | 手持ち | — | U2 の 9.4 V 調整に必須 |

### (c) カメラ側

| 部品 | 値/型番 | 数量 | 購入先 | 価格 | 備考 |
|---|---|---|---|---|---|
| ダミーバッテリー | Nikon **EP-5B** パワーコネクター | 1 | [Amazon.co.jp B0042VJSN8](https://www.amazon.co.jp/dp/B0042VJSN8) | ¥2,318 | 全対象機種共通（EN-EL15 系）。ケーブル端をネジ端子に直接つなぐ |
| レリーズケーブル（D7000〜D7500） | 3.5 mm ステレオプラグ → MC-DC2 型 | 1 | [Amazon.co.jp B0C9YLTTSX](https://www.amazon.co.jp/dp/B0C9YLTTSX) | ¥926 | 「3.5mm-N3」。チップ / リング / スリーブの割り当てはテスターで確認 |
| レリーズケーブル（D800/D810、任意） | 2.5 mm → 10 ピン + 2.5 mm メス→3.5 mm オス変換 | 各 1 | [Amazon.co.jp B0D49L1SL3](https://www.amazon.co.jp/dp/B0D49L1SL3) + [B00KXMH1UW](https://www.amazon.co.jp/dp/B00KXMH1UW) | ¥1,701 + ¥580 | 3.5 mm 直の 10 ピンケーブルは国内に見当たらない |
| USB OTG アダプタ（§4.2 の確認用） | USB-C オス → USB-A メス | 1 | 手持ち / 量販店 | — | カメラ側は各機種の純正 USB ケーブル |

### (d) PCB 版で追加（後日、基板設計後に確定）

| 部品 | 値/型番 | 数量 | 購入先 | 備考 |
|---|---|---|---|---|
| プリント基板 | ShutterClock PCB v1.0 | 1 | JLCPCB | ガーバーは `pcb/` に置く |
| ネジ端子 2P 5.08 mm | TB111-2 | 2 | [秋月 102333](https://akizukidenshi.com/catalog/g/g102333/) ¥40 | J1 電池、J2 カメラ電源 |
| ピンソケット 1×7 | FH-1x7SG/RH | 2 | [秋月 104285](https://akizukidenshi.com/catalog/g/g104285/) ¥20 | XIAO を差し替え可能に |
| ピンソケット 1×4 | FH-1x4SG/RH | 1 | [秋月 110099](https://akizukidenshi.com/catalog/g/g110099/) ¥20 | MBC2596-01 用（単ピンに切って使う） |
| OS-CON 470 µF / 16 V | 16SEPC470M | 1 | [秋月 108292](https://akizukidenshi.com/catalog/g/g108292/) ¥80 | 任意。C3 に並列（低温 ESR 対策） |

## 3. 概算（ブレッドボード試作 1 台）

- 秋月: 約 ¥9,000（XIAO ¥1,780、MBC2596-01 ×2 ¥3,800、ブレッドボード ¥1,980、その他の袋物 ¥1,500 程度）
- Amazon: 約 ¥3,300（EP-5B ¥2,318 + レリーズケーブル ¥926）。D800/D810 用を足すと +¥2,300
- 抵抗・ツェナー・コンデンサは 10〜100 本袋なので、2 台目以降はほぼ XIAO + MBC2596-01 + EP-5B + ケーブルの約 ¥7,000 で済みます

## 4. 発注前の注意

- MBC2596-01 は在庫僅少（10 月中旬入荷予定）。先に注文しておくか、入荷を待つ。
- 1N5822 は 3 A 定格です。ブレッドボードで撮影時の発熱を触って確かめ、気になれば 2 本並列にします（10 本入りなので手持ちで足ります）。
- 2SJ334 の在庫は潤沢ですが、2SK4017 は「10 月上旬入荷予定」の表示が出ています（在庫数は十分）。

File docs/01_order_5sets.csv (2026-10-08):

購入先 | コード | 品名 | 1台あたり個数 | 販売単位(個/袋) | 注文数(袋/個) | 単価(円) | 小計(円) | 備考
秋月 | 117341 | Seeed XIAO nRF52840（非Sense） | 1 | 1 | 6 | 1780 | 10680 | 5台+予備1
秋月 | 113996 | NJW4181U3-33B 3.3V LDO（SOT-89） | 1 | 1 | 10 | 60 | 600 | 5台+予備5（表面実装・小さいので余分に）
秋月 | 131750 | MBC2596-01 LM2596降圧モジュール | 1 | 1 | 6 | 1900 | 11400 | 5台+予備1。在庫僅少（10月中旬入荷）
秋月 | 115414 | 2SJ334 P-ch MOSFET 10個入 | 3 | 10 | 2 | 990 | 1980 | 15個必要→20個
秋月 | 107597 | 2SK4017 N-ch MOSFET | 3 | 1 | 16 | 30 | 480 | 15個必要+予備1
秋月 | 115169 | GDZJ15C 15Vツェナー 10本入 | 3 | 10 | 2 | 90 | 180 | 15本必要→20本
秋月 | 115721 | BZX55C9V1 9.1Vツェナー 20本入 | 1 | 20 | 1 | 100 | 100
秋月 | 100941 | 1N4148 50本入 | 1 | 50 | 1 | 200 | 200
秋月 | 129633 | P4KE15A TVS 10本入 | 2 | 10 | 2 | 150 | 300 | 10本必要→20本（予備）
秋月 | 102229 | 1N5822 ショットキー 10本入 | 1 | 10 | 1 | 350 | 350
秋月 | 107131 | ガラス管ヒューズ MF51NR 5A 5.2x20 | 1 | 1 | 10 | 40 | 400 | 5本+交換用5本
秋月 | 110521 | ヒューズクリップ FUC-03A | 2 | 1 | 12 | 20 | 240 | 10個必要+予備2
秋月 | 111011 | 0.1Ω 3W 電流検出抵抗 RSMF3BR100F | 1 | 1 | 6 | 20 | 120
秋月 | 113765 | PC817 フォトカプラ（Sharp） | 2 | 1 | 12 | 30 | 360 | 在庫僅少。無ければ UPC817CG 116090（¥15）
秋月 | 109060 | 3.5mmステレオジャック MJ-8435 | 1 | 1 | 6 | 90 | 540
秋月 | 103647 | タクトスイッチ 6mm | 1 | 1 | 6 | 15 | 90
秋月 | 116871 | 100μF/50V ハイブリッド Rubycon PZF（C1） | 1 | 1 | 6 | 80 | 480
秋月 | 108155 | 10μF/50V 積セラ 5mm（C2） | 1 | 1 | 6 | 60 | 360
秋月 | 114096 | 4700μF/16V Rubycon ZLH（C3） | 1 | 1 | 6 | 100 | 600
秋月 | 108152 | 2.2μF/50V 積セラ 5mm（C4） | 1 | 1 | 6 | 30 | 180
秋月 | 113582 | 0.1μF/50V 積セラ 10個入（C6-C8） | 3 | 10 | 2 | 100 | 200 | 15個必要→20個
秋月 | 125101 | カーボン抵抗 1/4W 100Ω 100本入 | 3 | 100 | 1 | 200 | 200 | R4,R20,R21
秋月 | 125102 | カーボン抵抗 1/4W 1kΩ 100本入 | 4 | 100 | 1 | 100 | 100 | R6-R9
秋月 | 125103 | カーボン抵抗 1/4W 10kΩ 100本入 | 1 | 100 | 1 | 100 | 100 | R14
秋月 | 125104 | カーボン抵抗 1/4W 100kΩ 100本入 | 5 | 100 | 1 | 200 | 200 | R2,R10-R13
秋月 | 125333 | カーボン抵抗 1/4W 33kΩ 100本入 | 2 | 100 | 1 | 200 | 200 | R16,R18
秋月 | 125473 | カーボン抵抗 1/4W 47kΩ 100本入 | 1 | 100 | 1 | 200 | 200 | R5。コード要確認
秋月 | 125105 | カーボン抵抗 1/4W 1MΩ 100本入 | 3 | 100 | 1 | 200 | 200 | R1,R15,R17
秋月 | 107956 | カーボン抵抗 1W 10Ω 100本入 | 1 | 100 | 1 | 350 | 350 | R19
秋月 | 102333 | ターミナルブロック 2P 5.08mm TB111-2 | 2 | 1 | 12 | 40 | 480 | J1,J2
秋月 | 104285 | ピンソケット 1x7（XIAO用） | 2 | 1 | 12 | 20 | 240
秋月 | 110099 | ピンソケット 1x4（降圧モジュール用） | 1 | 1 | 6 | 20 | 120
秋月 | 100167 | ピンヘッダ 1x40 | 0 | 1 | 3 | 35 | 105 | JP1/JP2・モジュール足・ブレッドボード用
秋月 | 103691 | ジャンパーピン（2.54mm） | 2 | 1 | 0 | 0 | 0 | コード・価格要確認。JP1/JP2用に10個
秋月 | 100285 | ブレッドボード 830穴 EIC-102BJ | 0 | 1 | 1 | 1980 | 1980 | 試作用（1台分）
秋月 | 130088 | ジャンパワイヤセット | 0 | 1 | 1 | 300 | 300 | 試作用
秋月 | 110835 | SOT-89変換基板 AE-SOT89 10枚入 | 0 | 10 | 1 | 70 | 70 | 試作用
Amazon | B0042VJSN8 | Nikon EP-5B パワーコネクター | 1 | 1 | 5 | 2318 | 11590 | 5個セット B0042VJSN8 の5-pack ¥11,590 も同額
Amazon | B0C9YLTTSX | 3.5mm→MC-DC2 レリーズケーブル（3.5mm-N3） | 1 | 1 | 5 | 926 | 4630 | D7000〜D7500用
Amazon | B0D49L1SL3 | 2.5mm→10ピン レリーズケーブル（任意） | 0 | 1 | 0 | 1701 | 0 | D800/D810を使う場合のみ。+変換 B00KXMH1UW ¥580
秋月 |  | 小計 |  |  |  |  | 34685
Amazon |  | 小計 |  |  |  |  | 16220
合計 |  |  |  |  |  |  | 50905 | 送料・ジャンパーピン除く

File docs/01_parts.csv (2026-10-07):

区分 | 記号 | 部品 | 値/型番 | 数量 | 購入先リンク | 備考
回路 | A1 | マイコン（BLE） | Seeed XIAO nRF52840（非Sense） | 1 | https://akizukidenshi.com/catalog/g/g117341/ | ¥1780。予備+1推奨
回路 | U1 | 3.3V LDO（常時ON） | NJW4181U3-33B (SOT-89) | 1 | https://akizukidenshi.com/catalog/g/g113996/ | ¥60。表面実装。ブレッドボードではAE-SOT89に載せる
回路 | U2 | カメラ用9V降圧 | MBC2596-01 (LM2596-ADJ) | 2 | https://akizukidenshi.com/catalog/g/g131750/ | ¥1900。1個予備。在庫僅少（10月中旬入荷）。9.4Vに調整・LED除去
回路 | Q1,Q2,Q5 | P-ch MOSFET | 2SJ334 | 3 | https://akizukidenshi.com/catalog/g/g102846/ | ¥110。G-D-S
回路 | Q3,Q6,Q7 | N-ch MOSFET | 2SK4017(Q) | 3 | https://akizukidenshi.com/catalog/g/g107597/ | ¥30。G-D-S
回路 | ZD1,ZD2,ZD3 | 15Vツェナー | GDZJ15C 500mW | 3 | https://akizukidenshi.com/catalog/g/g115169/ | 10本¥90
回路 | ZD4 | 9.1Vツェナー（時計保持フォロワ基準） | BZX55C9V1 500mW | 1 | https://akizukidenshi.com/catalog/g/g115721/ | 20本¥100。1N4148と直列
回路 | D6 | ZD4と直列 | 1N4148 | 1 | https://akizukidenshi.com/catalog/g/g100941/ | 50本¥200
回路 | D1,D2 | TVS（2本直列） | P4KE15A | 2 | https://akizukidenshi.com/catalog/g/g129633/ | 10本¥150
回路 | D4 | ショットキー（U2出力逆流防止） | 1N5822 40V3A | 1 | https://akizukidenshi.com/catalog/g/g102229/ | 10本¥350
回路 | F1 | ヒューズ | MF51NR 250V5A 5.2x20mm | 1 | https://akizukidenshi.com/catalog/g/g107131/ | ¥40
回路 | F1ホルダ | ヒューズクリップ | FUC-03A | 2 | https://akizukidenshi.com/catalog/g/g110521/ | ¥20。2個で1本分
回路 | R3 | 電流検出抵抗 | 0.1Ω 3W ±1% RSMF3BR100F | 1 | https://akizukidenshi.com/catalog/g/g111011/ | ¥20
回路 | U3,U4 | フォトカプラ | PC817 (PC817X3NSZ1B) | 2 | https://akizukidenshi.com/catalog/g/g113765/ | ¥30。在庫僅少。代替UPC817CG 116090
回路 | J3 | 3.5mmステレオジャック | MJ-8435 | 1 | https://akizukidenshi.com/catalog/g/g109060/ | ¥90
回路 | JP1,JP2 | ジャンパ（USB時外す/常時ON） | ピンヘッダ1x2+ジャンパピン | 2 | https://akizukidenshi.com/catalog/g/g103691/ | ジャンパピンのコード要確認
回路 | SW1 | タクトスイッチ | 6mm DTS-63-N-V-BLK | 1 | https://akizukidenshi.com/catalog/g/g103647/ | ¥15
回路 | C1 | 入力バルク | 100μF/50V ハイブリッド Rubycon PZF | 1 | https://akizukidenshi.com/catalog/g/g116871/ | ¥80
回路 | C2 | U1入力RC | 10μF/50V 積セラ 5mm | 1 | https://akizukidenshi.com/catalog/g/g108155/ | ¥60
回路 | C3 | カメラ9V側バルク | 4700μF/16V Rubycon ZLH | 1 | https://akizukidenshi.com/catalog/g/g114096/ | ¥100
回路 | C4 | U1出力 | 2.2μF/50V 積セラ 5mm | 1 | https://akizukidenshi.com/catalog/g/g108152/ | ¥30
回路 | C6-C8 | パスコン・ADCフィルタ | 0.1μF/50V 積セラ | 3 | https://akizukidenshi.com/catalog/g/g113582/ | 10個¥100
回路 | R4 | U1入力RC | 100Ω 1/4W | 1 | https://akizukidenshi.com/catalog/g/g125101/ | 100本¥200
回路 | R20,R21 | J3チップ/リング直列 | 100Ω 1/4W | 2 | https://akizukidenshi.com/catalog/g/g125101/ | R4と同じ袋
回路 | R6-R9 | フォトカプラLED直列/ゲート直列 | 1kΩ 1/4W | 4 | https://akizukidenshi.com/catalog/g/g125102/ | 100本¥100
回路 | R10-R13,R2 | プルダウン/プルアップ/分圧下 | 100kΩ 1/4W | 5 | https://akizukidenshi.com/catalog/g/g125104/ | 100本¥200
回路 | R5 | ZD4バイアス（KA_SWから） | 47kΩ 1/4W | 1 | https://akizukidenshi.com/catalog/g/g125473/ | 100本¥200。コード要確認
回路 | R16,R18 | Q2/Q5ゲート直列 | 33kΩ 1/4W | 2 | https://akizukidenshi.com/catalog/g/g125333/ | 100本¥200
回路 | R19 | Q7ドレイン突入制限 | 10Ω 1W カーボン | 1 | https://akizukidenshi.com/catalog/g/g107956/ | 100本¥350
回路 | R1,R15,R17 | 分圧上/Q1ゲート/C3ブリーダ | 1MΩ 1/4W | 3 | https://akizukidenshi.com/catalog/g/g125105/ | 100本¥200
回路 | R14 | A1フィルタ | 10kΩ 1/4W | 1 | https://akizukidenshi.com/catalog/g/g125103/ | 100本¥100
ブレッドボード | - | ブレッドボード830穴 | EIC-102BJ | 1 | https://akizukidenshi.com/catalog/g/g100285/ | ¥1980
ブレッドボード | - | ジャンパワイヤ | 60本以上セット | 1 | https://akizukidenshi.com/catalog/g/g130088/ | ¥300
ブレッドボード | - | SOT-89変換基板 | AE-SOT89 | 1 | https://akizukidenshi.com/catalog/g/g110835/ | 10枚¥70
ブレッドボード | - | ピンヘッダ1x40 | PH-1x40SG | 1 | https://akizukidenshi.com/catalog/g/g100167/ | ¥35
カメラ側 | - | ダミーバッテリー | Nikon EP-5B | 1 | https://www.amazon.co.jp/dp/B0042VJSN8 | ¥2318
カメラ側 | - | レリーズケーブル（D7000-D7500） | 3.5mm → MC-DC2型（3.5mm-N3） | 1 | https://www.amazon.co.jp/dp/B0C9YLTTSX | ¥926
カメラ側 | - | レリーズケーブル（D800/D810 任意） | 2.5mm → 10ピン | 1 | https://www.amazon.co.jp/dp/B0D49L1SL3 | ¥1701
カメラ側 | - | 変換アダプタ（D800/D810 任意） | 2.5mmメス → 3.5mmオス | 1 | https://www.amazon.co.jp/dp/B00KXMH1UW | ¥580
PCB | J1,J2 | ネジ端子2P 5.08mm | TB111-2 | 2 | https://akizukidenshi.com/catalog/g/g102333/ | ¥40
PCB | A1ソケット | ピンソケット1x7 | FH-1x7SG/RH | 2 | https://akizukidenshi.com/catalog/g/g104285/ | ¥20
PCB | U2ソケット | ピンソケット1x4 | FH-1x4SG/RH | 1 | https://akizukidenshi.com/catalog/g/g110099/ | ¥20
PCB | - | OS-CON 470μF/16V（任意） | 16SEPC470M | 1 | https://akizukidenshi.com/catalog/g/g108292/ | ¥80

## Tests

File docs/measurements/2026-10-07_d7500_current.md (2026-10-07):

# D7500 supply current — 2026-10-07

Spec §5 M1 (standby / off current), M2 (shot profile), M4 (power-up behaviour).
Spec U3, U4, U8, U9, U28.

Setup: bench PSU **9.00 V** → **picowatt** (INA228, 15 mΩ, ADCRANGE=0, `--preset fast`,
3200 Sa/s, stored zero/gain calibration applied) → EP-5B → **Nikon D7500**.
No ShutterClock hardware; shots released by hand with a wired remote. Image review
(playback menu) was **off** in all runs. Sensor cleaning setting: cleans at both power-switch
ON and OFF (seen in run 2).
PSU current limit 4 A. **With the limit at 2 A the camera showed "Err" and did not fire**
(user observation before run 1).

Command: `picowatt-cli --seconds N --csv runX.csv --preset fast --adcrange 0 --cal`.
Events below = current > 20 mA, gaps < 1 s merged. A·s = charge at 9 V (1 A·s = 0.278 mAh).

## Runs

| Run | Start | Focus | Standby timer (c2) | Content |
|---|---|---|---|---|
| 1 | 13:05 | AF | 6 s (default) | switch OFF → ON → 3 shots. Camera had asked for date/time at power-on (**clock had been reset**); the user set it during the ON event, so that event is long |
| 2 | 13:34 | AF | 6 s | clean repeat of run 1, + switch OFF at the end |
| 3 | 13:43 | AF | 4 s (minimum) | aborted after 3 shots (lens was on AF; kept for the c2 comparison) |
| 4 | 13:45 | **MF** | 4 s | 3 shots (+1 accidental double shot), then PSU output OFF/ON twice with the power switch left ON |

## Summary

| Item | Value | Runs |
|---|---|---|
| Standby (switch ON, meter off) | **0.42 mA** (0.60 → 0.45 → 0.425 → 0.42 mA over the session) | 1–4 |
| Switch OFF | same as standby (604 vs 606 µA in run 1, 447 vs 441 µA in run 2) | 1, 2 |
| Shot, AF, c2 = 6 s | **3.2 A·s** (3.20 / 3.21 / 3.25), awake 12 s | 2 |
| Shot, AF, c2 = 4 s | **2.79 A·s** (2.78 / 2.79 / 2.80), awake 10 s | 3 |
| Shot, MF, c2 = 4 s | **2.71 A·s** (2.70 / 2.71 / 2.72), awake 10 s | 4 |
| Power switch ON | 3.6 A·s: ~2 s sensor cleaning at 0.5–0.8 A, then awake ~10 s | 2 |
| Power switch OFF | 1.2 A·s: ~2.2 s sensor cleaning at 0.5–0.8 A | 1, 2 |
| **PSU restored with switch ON** | **camera starts by itself** (display lit, user); 62 mA for 0.5 s, awake at +0.54 s, standby at +10.5 s; **no sensor cleaning**; 2.48 A·s | 4 |
| PSU restored + remote held fully pressed | **shutter fired at +1.95 s** after power-up (upper bound for boot-to-shot; the press started by hand right after power-up); 2.79 A·s in total | 4 |
| Peak current | 3.0–3.2 A per shot (one shot 3.8 A, one 4.1 A); 3.9 A at the switch-ON in run 1; > 2 A for 20–30 ms per shot | all |

The standby drift (0.60 → 0.42 mA, levelling off) is most likely the internal clock cell
recharging after the reset seen at the start of run 1. Not proven; re-check standby later.

## Shot profile (MF, run 4, `data/2026-10-07_d7500_run4_mf_shot_3200Hz.csv`)

| t from wake | Phase (interpretation) | Current |
|---|---|---|
| 0 | wake (half-press): single-sample spike | ~0.9 A |
| 0–0.11 s | awake, metering | ~220 mA |
| 0.11–0.15 s | mirror up | 2.4 A (peak 3.1 A) |
| 0.15–0.20 s | exposure | ~650 mA |
| 0.20–0.27 s | mirror down + shutter charge | 1.7–2.0 A (peak 2.3 A) |
| 0.27–0.32 s | processing / card write? | ~500 mA |
| 0.32 s → 5.4 s | awake, unknown (not image review — it was off) | 260–320 mA |
| 5.4 s → 9.7 s | meter on; length matches c2 = 4 s (6 s in runs 1–2) | ~225 mA |

With AF (run 1, `data/2026-10-07_d7500_run1_af_shot_3200Hz.csv`) there is an extra
1.4–1.6 A segment of ~130 ms before the release (AF drive), but the per-shot charge differs by
only ~0.08 A·s (3 %). The bulk of the charge is the camera staying awake after the shot
(~10 s at 220–320 mA ≈ 2.4 A·s, ≈ 85 %).

## Power-up behaviour (M4)

- PSU output off → the 9 V node decays over ~2.4 s (PSU output capacitance).
- PSU output on with the power switch ON: 62 mA for 0.54 s (boot), then awake as after a
  switch-ON but **without** the 2 s sensor cleaning; standby after 10.5 s.
- With the remote held fully pressed from power-up the shutter fired at **+1.95 s**
  (`data/2026-10-07_d7500_run4_powerup_shot_3200Hz.csv`). Firmware can therefore either wait
  ~2–2.5 s after enabling the supply, or assert AF + SHUTTER from power-up until the shot is
  detected. Tune with ShutterClock on the bench.
- Unknown: when the card write is really finished (needed before cutting power after a shot);
  whether the camera still releases when its clock has been reset and the date prompt is shown.

## What this means

- **Peak current (U28).** 3–4 A peaks, 2 A limit → "Err". The 9 V path must source ≥ 4 A peaks
  with margin. Pololu D36V28F9 (2.6 A typ.) is not enough; D36V50F9 (9 V, 5 A, same family,
  no-load 2–4 mA, sleep 10–20 µA/V) fits the peak.
- **Energy per day (U8)**, D7500, 6 shots/day, at 9 V:
  - always powered (switch ON, standby): 0.42 mA × 24 h + 6 × 2.7 A·s ≈ 10.1 + 4.5 =
    **≈ 15 mAh/day ≈ 0.13 Wh/day**, plus the regulator's own draw (D36V50F9 2–4 mA at 12 V ≈
    0.6–1.2 Wh/day — larger than the camera).
  - power per shot, cut right after the card write (~2.5 s on): ≈ 0.85 A·s per shot →
    **≈ 1.4 mAh/day ≈ 0.013 Wh/day** (+ regulator sleep unless a load switch is added).
  - For scale: a 12 V 20 Ah battery holds 240 Wh; a 10 W panel gives tens of Wh on a clear day.
    Both options are small against a solar-charged 12 V battery; they matter only when the
    panel is covered for months.
- **Cheap savings in the camera menu.** Standby timer 4 s instead of 6 s: −13 %. Image review
  was already off. For power-per-shot, set sensor cleaning to off (it does not run on a hard
  power-up anyway, but runs on every switch ON/OFF).

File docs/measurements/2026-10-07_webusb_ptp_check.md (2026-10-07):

# 2026-10-07 WebUSB(PTP)動作確認 — 手順と記録

仕様書 §4.2 / §5 M7 / U23。コードは書かずに、Google の web-gphoto2 デモで次の 2 点を確かめる。

1. Android の Chrome から WebUSB でカメラにつながり、撮影画像(またはライブビュー)を表示できるか
2. USB でつないだままでも、本体のシャッターボタン・有線リモートでレリーズできるか(本番のレリーズ経路を試しながら画像を取れるか)

必須機種の D7200・D7500 を優先する。任意機種(D7000 / D7100 / D800 / D810)は手元にあれば A だけでも見る。

## 持ち物

- Android スマホ(Chrome を最新に更新しておく)
- OTG アダプタ: USB-C オス → USB-A メス(スマホ側が micro-B なら micro-B → USB-A メス)
- 各カメラの純正 USB ケーブル(USB-A → カメラ側)
  - D7200 / D7100: 8 ピン独自形状(UC-E6 / UC-E17)
  - D7500: micro-B(UC-E20)
  - D7000: mini-B(UC-E4)
  - D800 / D810: USB 3.0 micro-B(USB 2.0 の micro-B ケーブルでも挿さる)
- 充電済みの電池、空きのある SD カード
- あれば有線リモート(MC-DC2、D800/D810 は 10 ピン用)

## A. web-gphoto2 デモでの接続・撮影

1. カメラの電源を入れる(レンズは MF、撮影モードは何でもよい)。
2. スマホとカメラを OTG アダプタ + USB ケーブルでつなぐ。
   - Android が「USB の用途」「このデバイスを開くアプリ」を聞いてきたら、**フォトやファイルなど他のアプリは選ばずに閉じる**(他のアプリがカメラを掴むと Chrome から使えない)。
3. Chrome で https://web-gphoto2.rreverser.com/ を開き、接続ボタンを押して、出てきた機器一覧からカメラを選ぶ。
4. 確認すること(ボタン名はデモの表示に従う):
   - 接続できるか。カメラの設定一覧が出るか
   - ライブビュー(プレビュー)が出るか
   - デモの撮影ボタンで撮影でき、撮った画像が表示されるか
5. つながらないときは、ケーブルを挿し直してから 3 をやり直す。エラー表示はそのまま書き留めるかスクリーンショットを撮る。

## B. USB 接続中のレリーズ(M7 の本題)

A でつながった状態のまま:

1. カメラ本体のシャッターボタンで撮れるか
2. 有線リモート(あれば)の半押し・全押しで撮れるか
3. B1・B2 で撮った画像に、デモの画面が反応するか(表示されなくても可。画像一覧から見られるかだけでも)
4. 何も操作せずに置いておくと、半押しタイマーオフ(表示消灯)になるか(接続中の消費電力に関係)
5. ケーブルを抜いたあと、カメラが普段どおり動くか

## C. 時間があれば(EP-5B と安定化電源があるとき)

安定化電源 9V → picowatt → EP-5B → カメラ で、仕様書 §5 の M1(待機電流)・M2(1 ショットの電流波形)・M4(給電し直したときに自動起動するか、撮影できるまでの時間)を見る。picowatt は既定設定でフルスケール約 4A。

## 記録

試した環境: スマホ機種 _____、Android _____、Chrome _____

| 機種 | A 接続 | A 設定一覧 | A ライブビュー | A 撮影 + 表示 | B1 本体シャッター | B2 有線リモート | B3 デモの反応 | B4 消灯 | B5 抜いた後 | メモ |
|---|---|---|---|---|---|---|---|---|---|---|
| D7200 | | | | | | | | | | |
| D7500 | - | - | - | - | ○(※) | | | | | ※OTG でつないだ状態でシャッターが切れた(本体 / リモートは未記録)。スマホ側の認識は未確認、「開くアプリ」の選択画面は出なかった。A は未実施 |
| D7000 | | | | | | | | | | |
| D7100 | | | | | | | | | | |
| D800 | | | | | | | | | | |
| D810 | | | | | | | | | | |

記入例: ○ / × / -(未実施)。× のときはエラー表示をメモ欄に。

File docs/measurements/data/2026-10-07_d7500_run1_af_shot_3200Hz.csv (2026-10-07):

t_s | vbus_V | current_A
70.30017 | 8.9941 | 0.001489
70.30048 | 9.0035 | 0.000385
70.30079 | 9.0008 | 0.001193
70.30111 | 8.9914 | 0.000297
70.30142 | 8.9895 | 0.000297
70.30167 | 9.0008 | 0.000297
70.30198 | 8.9932 | 0.001193
70.30229 | 8.9988 | 0.000985
70.30260 | 8.9961 | 0.000697
70.30291 | 8.9979 | 0.001089
70.30322 | 9.0018 | 0.001385
70.30347 | 9.0035 | 0.001385
70.30378 | 8.9988 | 0.000777
70.30409 | 9.0008 | -0.000191
70.30440 | 8.9998 | 0.000881
70.30471 | 8.9979 | 0.000193
70.30496 | 8.9979 | 0.000193
70.30527 | 8.9971 | 0.000985
70.30558 | 8.9922 | 0.000489
70.30589 | 8.9988 | 0.000697
70.30620 | 8.9988 | 0.000297
70.30651 | 8.9988 | 0.000193
70.30677 | 9.0027 | 0.000193
70.30708 | 8.9941 | 0.000297
70.30739 | 9.0045 | 0.001881
70.30770 | 8.9979 | 0.000593
70.30801 | 9.0027 | 0.000489
70.30826 | 8.9961 | 0.000489
70.30857 | 8.9988 | 0.000593
70.30888 | 8.9988 | 0.001089
70.30919 | 9.0035 | 0.000801
70.30950 | 8.9904 | 0.000297
70.30981 | 8.9941 | 0.000297
70.31007 | 8.9998 | 0.000297
70.31037 | 8.9979 | 0.001385
70.31068 | 8.9998 | 0.000881
70.31099 | 8.9941 | 0.000489
70.31130 | 8.9941 | 0.000489
70.31161 | 8.9961 | 0.001089
70.31187 | 9.0008 | 0.001089
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

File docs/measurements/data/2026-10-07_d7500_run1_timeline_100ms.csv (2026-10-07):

t_s | mean_A | max_A | vmin_V
0.0 | 0.00061 | 0.0022 | 8.9865
0.1 | 0.00064 | 0.0023 | 8.9857
0.2 | 0.00063 | 0.0022 | 8.9848
0.3 | 0.00059 | 0.0020 | 8.9865
0.4 | 0.00057 | 0.0023 | 8.9828
0.5 | 0.00060 | 0.0020 | 8.9857
0.6 | 0.00064 | 0.0022 | 8.9885
0.7 | 0.00056 | 0.0023 | 8.9838
0.8 | 0.00059 | 0.0023 | 8.9848
0.9 | 0.00056 | 0.0026 | 8.9865
1.0 | 0.00065 | 0.0022 | 8.9838
1.1 | 0.00065 | 0.0026 | 8.9875
1.2 | 0.00063 | 0.0023 | 8.9875
1.3 | 0.00059 | 0.0033 | 8.9857
1.4 | 0.00065 | 0.0023 | 8.9885
1.5 | 0.00057 | 0.0019 | 8.9857
1.6 | 0.00062 | 0.0023 | 8.9875
1.7 | 0.00065 | 0.0023 | 8.9838
1.8 | 0.00060 | 0.0022 | 8.9848
1.9 | 0.00068 | 0.0019 | 8.9838
2.0 | 0.00062 | 0.0023 | 8.9875
2.1 | 0.00064 | 0.0023 | 8.9865
2.2 | 0.00062 | 0.0019 | 8.9875
2.3 | 0.00058 | 0.0021 | 8.9857
2.4 | 0.00063 | 0.0023 | 8.9865
2.5 | 0.00060 | 0.0021 | 8.9865
2.6 | 0.00059 | 0.0021 | 8.9848
2.7 | 0.00063 | 0.0022 | 8.9857
2.8 | 0.00060 | 0.0021 | 8.9875
2.9 | 0.00065 | 0.0023 | 8.9857
3.0 | 0.00063 | 0.0021 | 8.9865
3.1 | 0.00058 | 0.0019 | 8.9865
3.2 | 0.00060 | 0.0019 | 8.9857
3.3 | 0.00064 | 0.0021 | 8.9865
3.4 | 0.00063 | 0.0020 | 8.9885
3.5 | 0.00054 | 0.0019 | 8.9857
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

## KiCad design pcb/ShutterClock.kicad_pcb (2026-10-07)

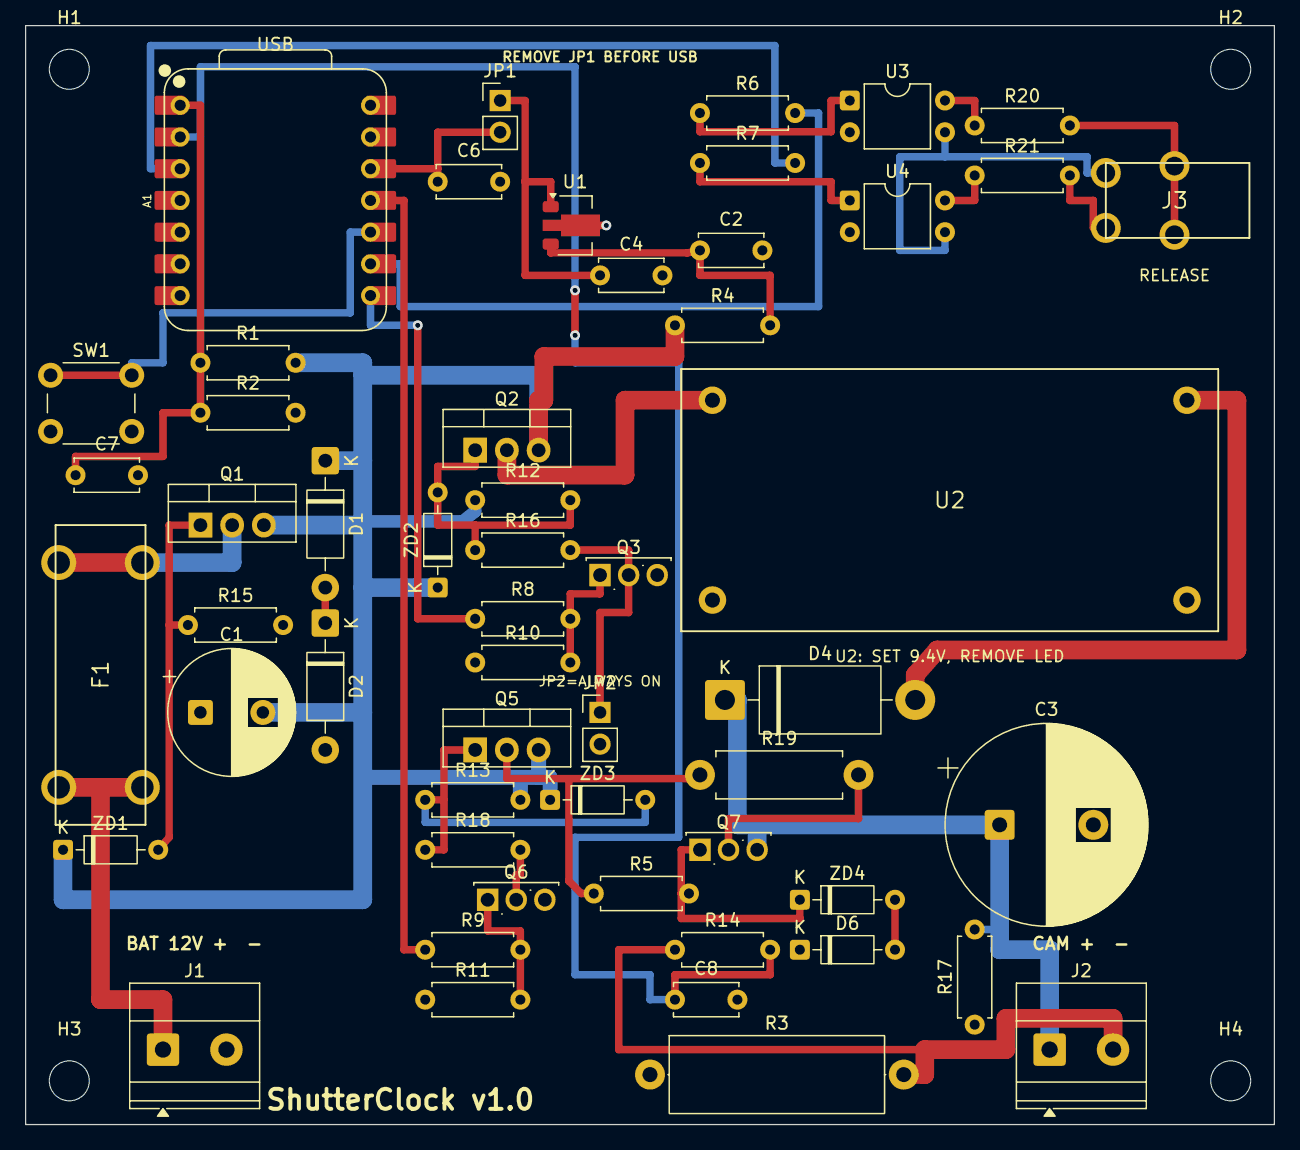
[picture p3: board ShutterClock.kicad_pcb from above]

Board: 2 copper layers, 100.0 x 88.0 mm, 58 parts (0 on the bottom side), 37 nets.

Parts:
A1: XIAO nRF52840; XIAO-nRF52840-DIP
C1: 100u/50V; CP_Radial_D10.0mm_P5.00mm
C2: 10u; C_Disc_D5.0mm_W2.5mm_P5.00mm
C3: 4700u/16V; CP_Radial_D16.0mm_P7.50mm
C4: 2.2u; C_Disc_D5.0mm_W2.5mm_P5.00mm
C6, C7, C8: 0.1u; C_Disc_D5.0mm_W2.5mm_P5.00mm
D1, D2: P4KE15A; D_DO-41_SOD81_P10.16mm_Horizontal
D4: 1N5822; D_DO-201AD_P15.24mm_Horizontal
D6: 1N4148; D_DO-35_SOD27_P7.62mm_Horizontal
F1: 5A; FUC-03A_x2_5x20
H1, H2, H3, H4: M3; MountingHole_3.2mm_M3
J1: BATTERY 12V; TerminalBlock_Phoenix_MKDS-1,5-2-5.08_1x02_P5.08mm_Horizont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
J2: CAMERA EP-5B; TerminalBlock_Phoenix_MKDS-1,5-2-5.08_1x02_P5.08mm_Horizont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
J3: 3.5mm RELEASE; MJ-8435
JP1: JP1 3V3; PinHeader_1x02_P2.54mm_Vertical
JP2: JP2 ALWAYS ON; PinHeader_1x02_P2.54mm_Vertical
Q1: 2SJ334 REV; TO-220-3_Vertical
Q2: 2SJ334 CAM; TO-220-3_Vertical
Q3, Q6: 2SK4017; TO-251-3_Vertical
Q5: 2SJ334 KA; TO-220-3_Vertical
Q7: 2SK4017 KA; TO-251-3_Vertical
R1, R15, R17: 1M; R_Axial_DIN0207_L6.3mm_D2.5mm_P7.62mm_Horizontal
R2, R10, R11, R12, R13: 100k; R_Axial_DIN0207_L6.3mm_D2.5mm_P7.62mm_Horizontal
R3: 0.1R 3W; R_Axial_DIN0617_L17.0mm_D6.0mm_P20.32mm_Horizontal
R4, R20, R21: 100; R_Axial_DIN0207_L6.3mm_D2.5mm_P7.62mm_Horizontal
R5: 47k; R_Axial_DIN0207_L6.3mm_D2.5mm_P7.62mm_Horizontal
R6, R7, R8, R9: 1k; R_Axial_DIN0207_L6.3mm_D2.5mm_P7.62mm_Horizontal
R14: 10k; R_Axial_DIN0207_L6.3mm_D2.5mm_P7.62mm_Horizontal
R16, R18: 33k; R_Axial_DIN0207_L6.3mm_D2.5mm_P7.62mm_Horizontal
R19: 10R 1W; R_Axial_DIN0411_L9.9mm_D3.6mm_P12.70mm_Horizontal
SW1: TEST; SW_PUSH_6mm
U1: NJW4181U3-33B; SOT-89-3
U2: MBC2596-01 9.4V; MBC2596-01
U3: PC817 SHUTTER; DIP-4_W7.62mm
U4: PC817 AF; DIP-4_W7.62mm
ZD1, ZD2, ZD3: 15V; D_DO-35_SOD27_P7.62mm_Horizontal
ZD4: 9.1V; D_DO-35_SOD27_P7.62mm_Horizontal

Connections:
3V3_LDO: C4.1, JP1.1, U1.1
3V3_SYS: A1.12, C6.1, JP1.2
A1_NODE: A1.2, C8.1, R14.2
ADC_NODE: A1.1, C7.1, R1.1, R2.1
AF_C: R21.1, U4.4
AF_DRV: A1.3, R7.2
AF_LED_A: R7.1, U4.1
BAT_RAW: F1.1, J1.1
BTN: A1.10, SW1.1
BUCK_IN: Q2.2, U2.INP
BUCK_OUT: D4.2, U2.OUTP
CAM_EN: A1.8, R8.1
CAM_N: J2.2, R3.2, R14.1
CAM_P: C3.1, D4.1, J2.1, Q7.3, R17.2
F_OUT: F1.2, Q1.2
GND: A1.13, C1.1, C2.2, C3.2, C4.2, C6.2, C7.2, C8.2, D2.2, D6.1, J1.2, JP2.2, Q3.3, Q6.3, R2.2, R3.1, R10.1, R11.1, R15.2, R17.1, SW1.2, U1.2, U2.INN, U2.OUTN, U3.2, U4.2
JACK_RING: J3.3, R21.2
JACK_SLEEVE: J3.1, U3.3, U4.3
JACK_TIP: J3.2, R20.2
KA_EN: A1.11, R9.1
KA_SW: Q5.2, R5.1, R19.1
LDO_IN: C2.1, R4.2, U1.3
Q1_G: Q1.1, R15.1, ZD1.2
Q2_DRV: JP2.1, Q3.2, R16.2
Q2_G: Q2.1, R12.2, R16.1, ZD2.2
Q3_G: Q3.1, R8.2, R10.2
Q5_DRV: Q6.2, R18.2
Q5_G: Q5.1, R13.1, R18.1, ZD3.2
Q6_G: Q6.1, R9.2, R11.2
Q7_D: Q7.2, R19.2
Q7_G: Q7.1, R5.2, ZD4.1
SHUT_C: R20.1, U3.4
SHUT_DRV: A1.9, R6.2
SHUT_LED_A: R6.1, U3.1
TVS_MID: D1.2, D2.1
VIN: C1.2, D1.1, Q1.3, Q2.3, Q5.3, R1.2, R4.1, R12.1, R13.2, ZD1.1, ZD2.1, ZD3.1
ZD_MID: D6.2, ZD4.2

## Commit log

2026-10-06 Spec v0.2: target cameras (D7200/D7500 required, D7000/D7100/D800/D810 optional)
    Add the per-body table (EP-5B common, 3-wire release with MC-DC2-type or
    10-pin connector, USB connector per body), notes on the camera clock cell,
    the D36V28F9 EN pull-up, the 3.5 mm jack proposal (U27), and the procedure
    for tomorrow's WebUSB/PTP check with the web-gphoto2 demo.
2026-10-07 D7500 supply current measured; spec v0.3 (3.5 mm jack decided, peak current item)
    picowatt at 3200 Sa/s on a 9 V bench supply via EP-5B: standby equals
    switch-off at 0.60 mA, one shot 3.3 A*s with ~80 % spent awake after the
    shot, peaks 3.1 A per shot and 3.9 A at power-on (a 2 A supply limit makes
    the camera show Err). Adds U28 (camera-path peak current), closes U27.
    [2026-10-07_d7500_shot1_3200Hz.csv, 2026-10-07_d7500_timeline_100ms.csv]
2026-10-07 D7500: MF / standby-timer runs and power-up test; spec v0.4
    Standby 0.42 mA (drifting down from 0.60 mA after a clock reset), 2.7 A*s
    per shot with MF and a 4 s standby timer, sensor cleaning only on switch
    ON/OFF, the camera starts by itself when power returns with the switch ON
    and fires 1.95 s after power-up with the remote held. Peaks up to 4.1 A,
    so the camera regulator candidate moves to the D36V50F9.
    [2026-10-07_d7500_run1_af_shot_3200Hz.csv, 2026-10-07_d7500_run1_timeline_100ms.csv, 2026-10-07_d7500_run2_timeline_100ms.csv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]
2026-10-07 Spec v0.5: draft circuit and BOM from domestic suppliers
    Akizuki first, Switch Science second, no overseas orders. Camera 9 V from a
    Pololu D30V33MAS (the D36V50F9 is not sold in Japan), 3.3 V from a 40 V
    low-Iq LDO (RT9069 or NJW4183, surface mount), camera path cut by a
    high-side P-FET, 0.1 ohm low-side shunt for shot / write-done detection,
    ungated 1M/100k battery divider. Energy estimate for 12 shots/day: 45-65 Wh
    per year, within a 12 V 20 Ah lead-acid battery.
2026-10-07 Spec v0.6: through-hole only, DFR1015 + 4700 uF for the camera 9 V, two-stage 3.3 V
    User decisions: no surface-mount parts, screw terminal for the camera
    power output. Excess-charge calculation from the 17 measured shots shows a
    2.5 A-class regulator needs ~3.7 mA*s of capacitor support (4700 uF for a
    1 V droop), so the cheap DFRobot DFR1015 becomes the primary candidate with
    the D30V33MAS as fallback. 3.3 V: 2SK4017 source follower with a 9.1 V
    zener in front of the NJU7223F33 reused from SnowGauge.
2026-10-07 CLAUDE.md: v0.6 state (through-hole only, DFR1015 + 4700 uF, two-stage 3.3 V)
2026-10-07 Spec v0.7: camera 9 V from the Akizuki MBC2596-01 (LM2596-ADJ module)
    User's pick. Module datasheet and LM2596 datasheet checked: peak current
    limit 3.4-6.9 A with frequency-foldback limiting (no hiccup), Iq 5 mA when
    on, 40 V input, ON/OFF pin not brought out, power LED to be removed,
    trimpot set to 9.0 V. Worst measured shot needs only ~0.5 mA*s above
    3.3 A, so 4700 uF on the output is ample. DFR1015 / D30V33MAS kept as
    fallbacks. Notes the 24 Wh/yr cost of a daily 1 h clock-maintenance
    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
2026-10-07 Spec v0.8: NJW4181U3-33B on an AE-SOT89 adapter proposed for the 3.3 V rail
    User's pick, pending their decision. Datasheet checked: 5-35 V operating,
    40 V absolute max, Iq 9 uA typ / 20 uA max, 100 mA, thermal / overcurrent /
    reverse-current protection, ceramic output capacitor OK, pins VOUT-GND-VIN.
    Mounted on the Akizuki SOT-89 adapter so the PCB stays through-hole; 100 ohm
    + 10 uF RC in front because the 2x P4KE15A clamp can reach 42 V. The
    MOSFET-follower + NJU7223F33 chain becomes the fallback.
2026-10-07 Spec v0.9: SMD allowed (user assembles), NJW4181 direct, clock keep-alive path
    The user assembles ShutterClock personally, so the SnowGauge through-hole
    rule does not apply: the NJW4181U3-33B goes straight on the PCB (U14
    closed). The LM2596 module's 5 mA Iq makes a daily 1 h clock-maintenance
    power-on cost ~24 Wh/yr and no low-Iq 9 V regulator is sold domestically,
    so a separate micro-power path is proposed (U29): 2SJ334 switch, 2SK4017
    source follower with a zener reference, Schottky on the buck output to
    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
2026-10-07 Parts list for the breadboard prototype; spec v0.10
    docs/01_parts.md + CSV in the SnowGauge format with Akizuki codes, prices
    and stock checked on 2026-10-07. Schottky becomes 1N5822 (no 5 A
    through-hole part at Akizuki; peaks are 20-30 ms), keep-alive zener 12 V
    (no 11 V stocked). MBC2596-01 confirmed over DFR1015.
    [01_parts.csv]
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2026-10-07 PCB v1.0 draft: scripted KiCad board, DRC clean, gerbers and renders
    Spec v0.11 circuit on a 100 x 88 mm 2-layer board generated by
    pcb/generate_board.py + tracks.py (custom footprints for the MJ-8435 jack,
    FUC-03A fuse clips and the MBC2596-01 module). DRC: 0 errors, 0 unconnected.
    Not ordered: module hole positions are a placeholder, bench verification and
    a layout review are still pending. Pin map in pcb/README.md.
    [01_parts.csv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]
2026-10-07 pcb: move the BAT/CAM polarity silkscreen above the terminal blocks
    [ShutterClock-B_Cu.gbr, ShutterClock-B_Mask.gbr, ShutterClock-B_Paste.gbr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]
2026-10-08 PCB v1.0 ordered at JLCPCB (W2026100808086019); spec v0.12
2026-10-08 Order list for 5 sets (Akizuki + Amazon)
    [01_order_5sets.csv]
2026-10-11 Firmware scaffold: SnowGauge port with camera control, shot records, shot GATT (builds)
2026-10-11 Web Bluetooth app for ShutterClock (shot log, schedule + camera settings, test shot panel)
2026-10-16 Assembly guide for PCB v1.0 (placement map generated from the board, soldering order, power-up checks); spec v0.14; C1 silk erratum
    docs/02_assembly.md + docs/assembly/placement_top.png (extract_board.py with
    KiCad python, draw_placement.py with matplotlib). Found while writing it: C1
    pad 1 (square, silk +) is assigned to GND in generate_board.py; recorded as
    PCB v1.0 erratum (mount C1 + in the right pad), to fix in v1.1.
2026-10-16 Assembly guide: orientation card (what each polarised part looks like and which way it goes), appearance-based orientation table
2026-10-19 PCB v1.0 errata: U2 hole pattern 40 x 17.5 mm, F1 clip pins along the fuse axis; assembly guide workarounds
2026-10-20 Firmware: disable uart0/spi2/i2c1 in the overlay (their pinctrl claimed D7/D8/D9/D10 so CAM_EN never drove Q3); board #1 battery trim 980
    First full shot sequence on hardware with the D7500: boot 548 ms, idle 243 mA,
    peak 2.87 A at 310 ms, shot detected, awake 9.4 s, on 12.5 s.
2026-10-20 Bench log for board #1 (D7500): shot sequence, keep-alive 8.1 V, firmware fixes
2026-10-20 Bench: sleep current of board #1 (36-49 uA whole board, picowatt)
2026-10-20 App panel 4: one camera power toggle (60 min auto-off), test shot with result, ERASE; status streamed automatically. Firmware: drop an app-started camera hold when BLE disconnects, live timeout 2 h
2026-10-21 Spec v0.15: board #1 bench results, errata, firmware/app fixes; CLAUDE.md app state
2026-10-21 PCB v1.1: fix C1 polarity nets, U2 hole pattern (40 x 17.5 mm), F1 clip pins along the fuse axis (7.0 mm); ZD1 moved; DRC clean, gerbers, renders, placement map; spec v0.16
2026-10-21 Firmware: remove the scheduler hold-off after resets (the scheduler waits for the next slot anyway); keep the reset-loop halt, cleared by a BLE connection. App 2026-10-21b texts
2026-10-21 PCB v1.2: RX8900 RTC module + CR2032 holder + series diode on a bottom strip (100 x 100 mm), I2C on D4/D5; DRC clean, gerbers, renders, placement map; parts list, spec v0.17
2026-10-21 Firmware: defer the reset-counter clear to the system work queue (flash write from the BT connected callback crashed the board on every app connection); RX8900 external RTC driver + boot-time clock r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
    Driver and integration finished by an Opus subagent: VLF stays set in the chip
    until a successful set_time, get_time returns -ENODATA meanwhile; driver
    compiled into the app target; 'time' shows the external RTC state.
2026-10-21 CLAUDE.md: record the BT-callback flash-write lesson and current firmware
